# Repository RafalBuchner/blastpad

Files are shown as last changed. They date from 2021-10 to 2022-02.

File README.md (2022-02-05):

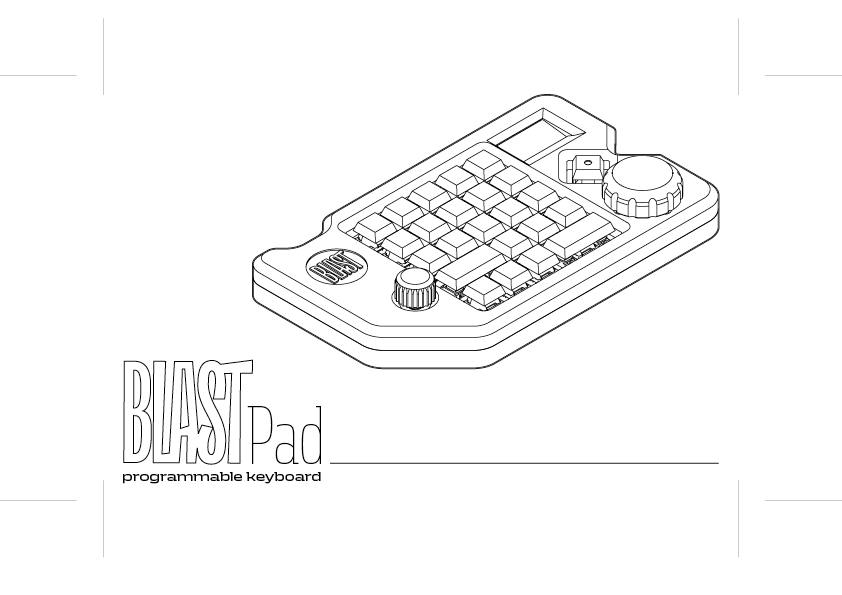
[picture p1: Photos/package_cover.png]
package_cover


# BLASTPad Documentation

**BLASTPad** is a macropad – a programmable keyboard with 23 customazible keys and 2 encoders (knobs). 

# Instruction

## Layout

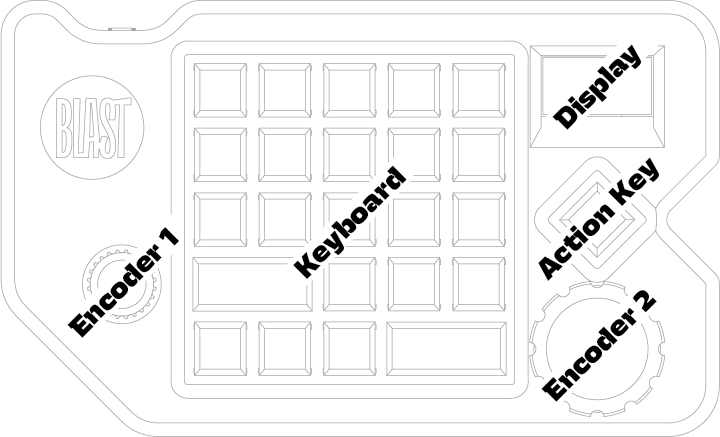
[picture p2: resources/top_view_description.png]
top_view_description


Keyborad's layout was designed to resamble the most left 5 columns of a standard keyborad with the exclusion of the top row (which usually contains all the _F_ keys together with _ESC_ key ). All of the keys are programmable, which means that with the help of a small desktop app you will be able to change behaviour of each key by assigning keystroke combinations to all of them.  Additionally **BLASTPad** has two rotary encoders, which also can trigger some keystroke actions.

## First Run

1. Connect your **BLASTPad** to your computer via USB MICRO B cable. New usb storage device called **BLASTPAD** should appear. We will talk about it more later.
2. Wait until **BLAST** logo will disappear.
3. You should see the similar data on the display:

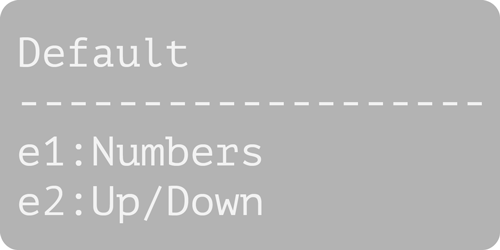
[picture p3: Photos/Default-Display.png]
Default-Display


- "Default" is a title of currently active **Preset**.
- "Numbers" is a title of an **Encoder Action** currently assigned to the **Encoder 1**
- "Up/Down" is a title of an **Encoder Action** currently assigned to the **Encoder 2**

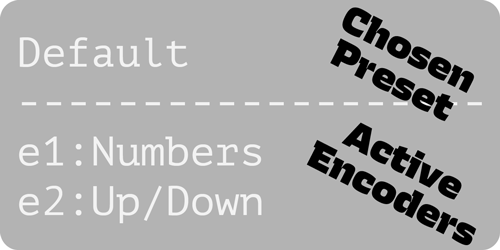
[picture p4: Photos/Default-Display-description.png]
Default-Display-description


### Encoder Basics

In next the chapter we will talk more about **Presets** and how to set them up together with the **Key and Encoder Actions**.  For now let's focus on the behaviour of the latter.

#### Changing the Encoder Actions:

Push the knob like it were a button.

You can see on the display that encoder changed it's title and therefore it changed its behaviour. Each **Preset** has its own set of "behaviours" that can be assigned to eighter **Encoder 1** or **Encoder 2** (see chapter **Creating and editing Presets** to learn how to create those behaviours).

There are two **types of Encoder Actions**:

- **"Left/Right" Encoder Action**

  >  In this action you have assigned two keystrokes to the encoder: one to the counterclockwise and the other one to the cockwise movements.
  >
  > Good example is the "Up/Down" action. Left movement performs "UP ARROW" keystroke, while right movement performs "DOWN ARROW" keystroke. Test it, for example, in some text editor. You will see that the cursor behaves in a similar way, as you would hit the arrow buttons.

- **"Carousel" Encoder Action**

  >"Numbers" is a good example of a carousel action. In this action when you rotate knob clockwise, it will execute numerical keystroke. With every step the keystroke will represent incremented digit starting from *0* (zero) until it will reach the *9*. After this, the counting will reset to *0*.
  >
  >If you'll rotate know counterclockwise, the operation will work almost the same. Except, this time instead of incrementing, it will decrement digits.

## Creating and editing Presets

**Preset** is a singular set of instructions, which determines what keystroke sequence will be triggered by your keys or encoders. You can store almost as many presets on your **BlastPad** as you want.

#### Maximum number of actions in the Preset:

Each **Preset** has actions assigned to the keys, which max number in the preset is equal to the number of the buttons in **BLASTPad**'s keyboard layout (23 – excluding the special lonely key on the right side of the device). Besides **Key Actions**, each preset can have **Encoder Actions**. Number of those is in theory limitless. You can switch between all of **Preset**'s **Encoder Actions** with just two physical encoders. 

#### BlastPadControl app

### MacOS

>  (Currently alpha pre-release version.)

#### Opening the app

Download the zip file from this site:

https://github.com/RafalBuchner/blastpad/releases/download/v0.0.0.1-alpha/BlastPadControl.macOS.zip

Or go to the main GitHub page of this project (https://github.com/RafalBuchner/blastpad) and look for the link in the download section of the documentation. 

Inside the unzipped folder you will find BlastPadControl executable file. Double click on it. The window like one below should appear:

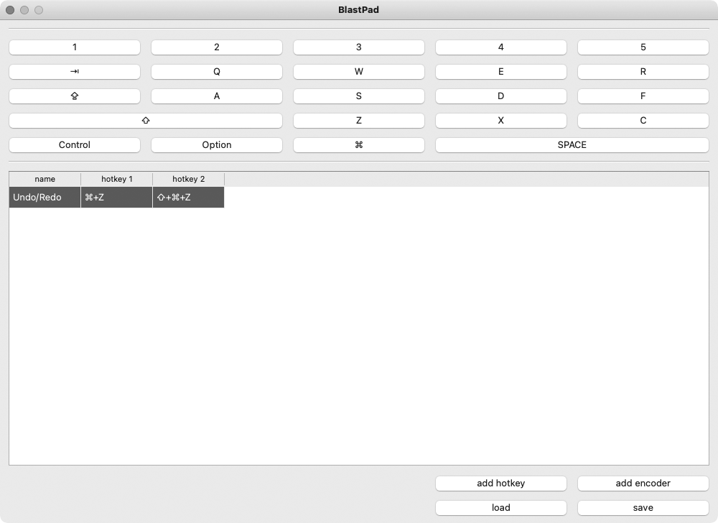
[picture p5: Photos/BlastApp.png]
BlastApp


This is the **Preset** Editor. It is divided into two sections. One is responsible for controling the **Key Actions**. The other one for creating and editing the **Encoder Actions**.

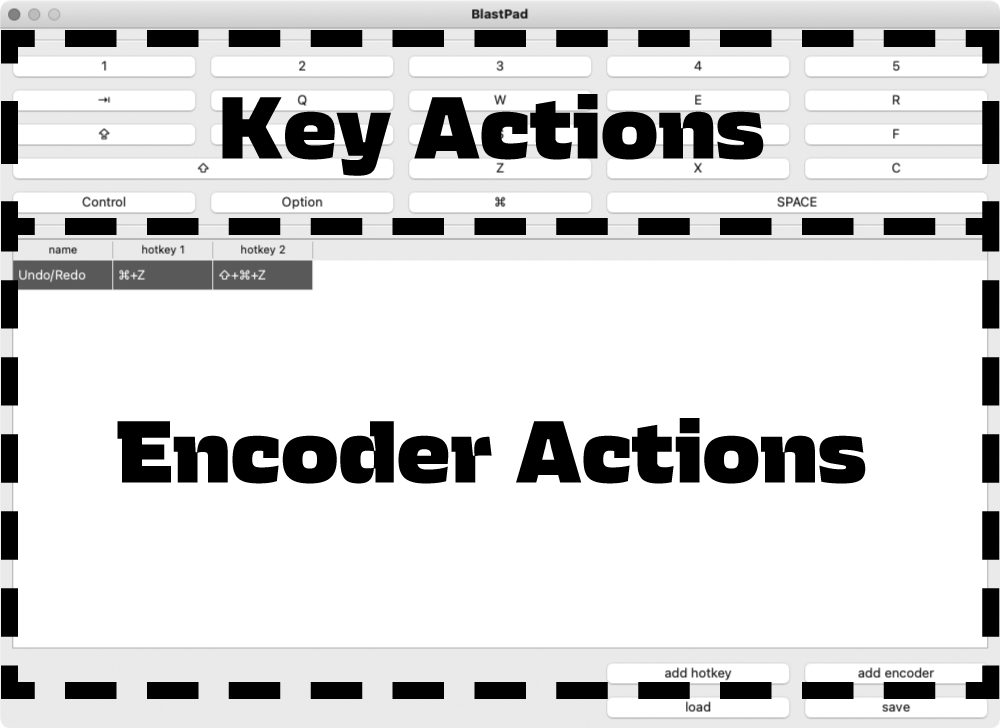
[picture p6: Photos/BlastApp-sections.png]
BlastApp-sections


### Key Actions Section

**The Key Actions Section**'s buttons recreates the **BlastPad**'s keyboard layout. If you click on the one of the buttons, the popup window will appear.

BlastApp-HotKeyPopUp

In this window you can assign pressed keystroke sequence to the previously selected button on the **Key Action Section**. 

Simply press some keystroke sequence on your everyday-regular-keyboard and press "ok" button (**IMPORTANT**: Pacience, This keystroke won't be triggered by the corresponding key on the **BLASTPad** device yet – we will talk about saving presets onto the device soon).

This way you can edit all of the buttons on the **Key Action Section** layout. It is super easy.

### Encoder Actions Section

**Encoder Actions Section** is a list, where each row represent different **Encoder Actions**. Each column cell (except the one reserved for the name) defines Keystroke/Hotkey.

- To create a new **Encoder Action** hit *"add encoder"* button. It will create a new row. 

- Double click on the cell with the title "new encoder" to set the **Encoder Action**'s name that will appear on the **BLASTPad**'s display.

- Click on one of the hotkey cells to assign keystroke sequence.

### Creating "Left/Right" Encoder Action

To create a **"Left/Right" Encoder Action** you have to assign 2 hotkeys to the encoder. One in the column "hotkey 1" and the otherone in the column "hotkey 2". 

The first one will be triggered when you rotate physical encoder counterclockwise. The second, whenever you rotate the same encoder in clockwise direction.

### Creating "Carousel" Encoder Action

To create a **"Carousel" Encoder Action** you have to assign any number of hotkeys, except 2.

If you want to have additional hotkey slots created, hit *"add hotkey"* button. You can add as many as you want.

### Saving presets onto the device

You save **Presets** as separate files with **.json* extension. 

Press *Save* button to create a **Preset** file. In order to save preset on your **BLASTPad** find the usb device with the same name and save the **Preset** into *"Configs"* folder. The name of the file will be used as a **Preset Title** on the **BlastPad**'s display, so name it accordingly to your needs.

### Changing the active Presets on the BlastPad device.

If you have more than one **Presets** you will be able to swich between the presets whenever you like!

It is super easy. Hold **Action Key** (the lonley key on the right side of the device). You will enter the **Preset Selection** menu. Now, rotate your **Encoder 1** while holding the key. This way you will switch between the **Presets**.

### Windows 

> (It is currently under construction. Beta version is coming very soon.)

# Downloads

## BlastPadControl

### [MacOS Download link](https://github.com/RafalBuchner/blastpad/releases/download/v0.0.0.1-alpha/BlastPadControl.macOS.zip)

## Photos

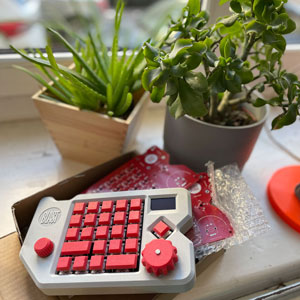
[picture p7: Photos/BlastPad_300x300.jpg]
BlastPad_300x300


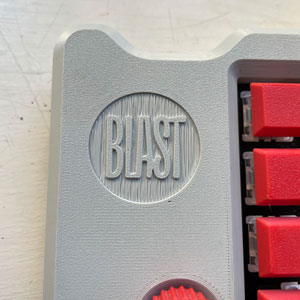
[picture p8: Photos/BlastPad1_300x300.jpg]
BlastPad1_300x300


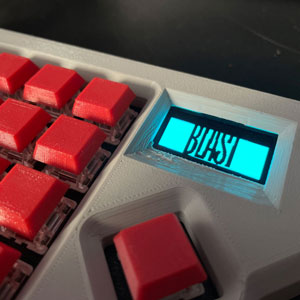
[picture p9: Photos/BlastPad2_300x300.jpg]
BlastPad2_300x300


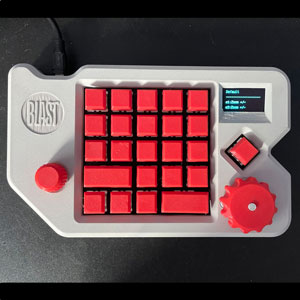
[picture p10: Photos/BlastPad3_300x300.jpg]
BlastPad3_300x300


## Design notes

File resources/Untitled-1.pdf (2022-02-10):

/.notdef AÁĂÂÄÀĀĄÅÃÆǼBCĆČÇĈĊDÐĎĐEÉĔĚÊËĖÈĒĘFGĞĜĢĠHĦĤIĲÍĬÎÏİÌĪĮĨJĴKĶLĹĽĻ ĿŁMNŃŇŅŊÑOÓŎÔÖÒŐŌØÕŒPÞQRŔŘŖSŚŠŞŜȘẞTŦŤŢȚUÚŬÛÜÙŰŪŲŮŨVWẂŴẄẀ XYÝŶŸỲZŹŽŻ/J.ss04/Jcircumflex.ss04/Q.ss05/R.ss06/Racute.ss06/Rcaron.ss06/uni0156. ss06 aáăâäàāąåãæǽbcćčçĉċdðďđeéĕěêëėèēęfgğĝģġhħĥiıíĭîï/i.loclTRK ìĳīįĩjȷĵkķĸlĺľ ļŀłmnńŉňņ ŋñoóŏôöòőōøõœpþqrŕřŗsśšşŝșßtŧťţțuúŭûüùűūųůũvwẃŵẅẁxyýŷÿỳzźžż/d.ss01/dcaron.ss01/ dcroat.ss01/i.ss01/dotlessi.ss01/iacute.ss01/ibreve.ss01/icircumflex.ss01/idieresis.ss01/i.locl-TRK.ss01/igrave.ss01/ij.ss01/imacron.ss01/iogonek.ss01/itilde.ss01/j.ss01/uni0237.ss01/jcircumflex.ss01/l.ss01/lacute.ss01/lcaron.ss01/uni013C.ss01/ldot.ss01/lslash.ss01/u.ss01/uacute. ss01/ubreve.ss01/ucircumflex.ss01/udieresis.ss01/ugrave.ss01/uhungarumlaut.ss01/umacron. ss01/uogonek.ss01/uring.ss01/utilde.ss01/y.ss01/yacute.ss01/ycircumflex.ss01/ydieresis.ss01/ ygrave.ss01/a.ss02/aacute.ss02/abreve.ss02/acircumflex.ss02/adieresis.ss02/agrave.ss02/ amacron.ss02/aogonek.ss02/aring.ss02/atilde.ss02/y.ss02/yacute.ss02/ycircumflex.ss02/ ydieresis.ss02/ygrave.ss02/g.ss03/gbreve.ss03/gcircumflex.ss03/uni0123.ss03/gdotaccent. ss03/f_f/f_f_i/f_f_l fifl/f_f_t.dlig/f_l.dlig/f_t.dlig/t_t.dlig/f_l.dlig.ss01/f_f_i.ss01/f_f_l.ss01/fi.ss01/ fl.ss01 ªºΔΩμπ0123456789➀➁➂➃➄➅➆➇➈➊➋➌➍➎➏➐➑➒/four.sansSerifCircled.ss07/four. sansSerifBlackCircled.ss07/four.ss07/zero.tf/one.tf/two.tf/three.tf/four.tf/five.tf/six.tf/seven.tf/eight.tf/nine.tf/four.tf.ss07/u1F10C/u1F10B ⁰¹²³⁴⁵⁶⁷⁸⁹⁄½⅓¼¾/uni2074.ss07 .,:;…!¡?¿·•*#/\/ exclamdown.case/questiondown.case/periodcentered.case/slash.case/backslash.case (){} []/parenleft.case/parenright.case/braceleft.case/braceright.case/bracketleft.case/bracketright.case -–—_/hyphen.case/endash.case/emdash.case ‚„“”‘’«»‹›”’/guillemotleft.case/guillemotright.case/guilsinglleft.case/guilsinglright.case ฿₿¢¤$€ƒ₹£¥⋅+−×÷=≠><≥≤±≈~¬^∞∫∏∑√ ∂µ%‰↑↗→↘↓↙←↖↔↕●○◊▯■□◽◾▲▶◀△▷◁@&¶§©®™°|¦†‡/bar.case/brokenbar.case/ampersand. ss10/ampersand.ss11 ̈̇̀
́̋/uni030C.alt ̧̨̂̌̆̊̃̄̒¨˙`´˝ˆˇ˘˚˜¯¸˛ ̦

/.notdef AÁĂÂÄÀĀĄÅǺÃÆǼBCĆČÇĈĊDÐĎĐEÉĔĚÊËĖÈĒĘFGĞĜĢĠHĦĤIĲÍĬÎÏİÌĪĮĨJĴKĶLĹĽĻĿŁM NŃŇŅŊÑOÓŎÔÖÒŐŌØǾÕŒPÞQRŔŘŖSŚŠŞŜȘẞTŦŤŢȚUÚŬÛÜÙŰŪŲŮŨVWẂŴẄẀXYÝŶŸỲZŹŽ Ż/K.ss01/uni0136.ss01/R.ss01/Racute.ss01/Rcaron.ss01/uni0156.ss01/Q.ss02/D.superior/O.superior/T.superior aáăâäàāąåǻãæǽbcćčçĉċdðďđeéĕěêëėèēęfgğĝģġhħĥiıíĭîï/i.loclTRK ìĳīįĩjȷĵkķĸlĺľļ ŀłmnńŉňņŋñoóŏôöòőōøǿõœpþqrŕřŗsśšşŝșßtŧťţțuúŭûüùűūųůũvwẃŵẅẁxyýŷÿỳzźžż/k.ss01/ uni0137.ss01/kgreenlandic.ss01/ae.ss03/aeacute.ss03/e.ss03/eacute.ss03/ebreve.ss03/ecaron. ss03/ecircumflex.ss03/edieresis.ss03/edotaccent.ss03/egrave.ss03/emacron.ss03/eogonek. ss03/oe.ss03/r.ss04/racute.ss04/rcaron.ss04/uni0157.ss04/y.ss05/yacute.ss05/ycircumflex.ss05/ ydieresis.ss05/ygrave.ss05 fiflªºΔΩμπ0123456789/zero.osf/one.osf/two.osf/three.osf/four.osf/five. osf/six.osf/seven.osf/eight.osf/nine.osf/two.osf.ss06/three.osf.ss06/two.ss06/three.ss06/zero.tf/ one.tf/two.tf/three.tf/four.tf/five.tf/six.tf/seven.tf/eight.tf/nine.tf/two.tf.ss06/three.tf.ss06/zero. tosf/one.tosf/two.tosf/three.tosf/four.tosf/five.tosf/six.tosf/seven.tosf/eight.tosf/nine.tosf/two. tosf.ss06/three.tosf.ss06 ¹²³⁴⁄½¼¾.,:;…!¡?¿·•*⁂#/\⁑/exclamdown.case/questiondown.case/periodcentered.case (){}[]-–—_/hyphen.case/endash.case/emdash.case ‚„“”‘’«»‹›”’/guillemotleft.case/ guillemotright.case/guilsinglleft.case/guilsinglright.case ¢¤$€ƒ£¥⋅+−×÷=≠><≥≤±≈~¬^∞∫Ω∆∏∑√ ∂µ%‰●○◊▯■□◽◾▲▶◀△▷◁⚪⚫@&¶§©®™°|¦†‡/ampersand.ss07 ̈̇
̀

́

̋
/uni030C.alt ̵̧̨̦

̂

̌

̆

̊

̃

̄

̒
¨˙`´˝ˆˇ˘˚˜¯¸˛/uni0308.
case/uni0307.case/gravecomb.case/acutecomb.case/uni030B.case/uni0302.case/uni030C.case/ uni0306.case/uni030A.case/tildecomb.case/uni0304.case/uni0328.case/uni0307.i/ringacutecomb/ringacutecomb.case

/.notdef AÁĂÂÄÀĀĄÅǺÃÆǼBCĆČÇĈĊDÐĎĐEÉĔĚÊËĖÈĒĘFGĞĜĢĠHĦĤIĲÍĬÎÏİÌĪĮĨJĴKĶLĹĽĻĿŁMNŃŇŅ ŊÑOÓŎÔÖÒŐŌØǾÕŒPÞQRŔŘŖSŚŠŞŜȘẞTŦŤŢȚUÚŬÛÜÙŰŪŲŮŨVWẂŴẄẀXYÝŶŸỲZŹŽŻ/Q.ss02/D. superior/O.superior/T.superior aáăâäàāąåǻãæǽbcćčçĉċdðďđeéĕěêëėèēęfgğĝģġhħĥiıíĭîï/i.loclTRK ìĳīįĩjȷĵkķĸlĺľļŀłmnńŉňņŋñoóŏôöòőōøǿõœpþqrŕřŗsśšşŝșßtŧťţțuúŭûüùűūųůũvwẃŵẅẁxyýŷÿỳzźžż/a. ss08/aacute.ss08/abreve.ss08/acircumflex.ss08/adieresis.ss08/agrave.ss08/amacron.ss08/aogonek. ss08/aring.ss08/aringacute.ss08/atilde.ss08 fiflªºΔΩμπ0123456789/zero.osf/one.osf/two.osf/three. osf/four.osf/five.osf/six.osf/seven.osf/eight.osf/nine.osf/two.osf.ss06/three.osf.ss06/two.ss06/three. ss06/zero.tf/one.tf/two.tf/three.tf/four.tf/five.tf/six.tf/seven.tf/eight.tf/nine.tf/two.tf.ss06/three.tf.ss06/ zero.tosf/one.tosf/two.tosf/three.tosf/four.tosf/five.tosf/six.tosf/seven.tosf/eight.tosf/nine.tosf/two. tosf.ss06/three.tosf.ss06 ¹²³⁴⁄½¼¾.,:;…!¡?¿·•*⁂#/\⁑/exclamdown.case/questiondown.case/periodcentered.case (){}[]-–—_/hyphen.case/endash.case/emdash.case ‚„“”‘’«»‹›”’/guillemotleft.case/guillemotright.case/guilsinglleft.case/guilsinglright.case ¢¤$€ƒ£¥⋅+−×÷=≠><≥≤±≈~¬^∞∫Ω∆∏∑√∂µ%‰●○◊▯■ □◽◾▲▶◀△▷◁⚪⚫@&¶§©®™°|¦†‡̈̇
̀

́

̋
/uni030C.alt ̵̧̨̦

̂

̌

̆

̊

̃

̄

̒
¨˙`´˝ˆˇ˘˚˜¯¸˛/uni0308.case/uni0307.case/gravecomb.case/ acutecomb.case/uni030B.case/uni0302.case/uni030C.case/uni0306.case/uni030A.case/tildecomb. case/uni0304.case/uni0328.case/uni0307.i/ringacutecomb/ringacutecomb.case

/.notdef AÁĂÂÄÀĀĄÅǺÃÆǼBCĆČÇĈĊDÐĎĐEÉĔĚÊËĖÈĒĘFGĞĜĢĠHĦĤIĲÍĬÎÏİÌĪĮĨJĴKĶLĹĽĻĿŁM NŃŇŅŊÑOÓŎÔÖÒŐŌØǾÕŒPÞQRŔŘŖSŚŠŞŜȘẞTŦŤŢȚUÚŬÛÜÙŰŪŲŮŨVWẂŴẄẀXYÝŶŸỲ ZŹŽŻ/K.ss03/uni0136.ss03/I.ss06/Iacute.ss06/Ibreve.ss06/Icircumflex.ss06/Idieresis.ss06/ Idotaccent.ss06/Igrave.ss06/Imacron.ss06/Iogonek.ss06/Itilde.ss06/J.ss06/Jcircumflex.ss06 aáăâäàāąåǻãæǽbcćčçĉċdðďđeéĕěêëėèēęfgğĝģġhħĥiıíĭîï/i.loclTRK ìĳīįĩjȷĵkķĸlĺľļŀłmnńŉňņŋñoóŏ ôöòőōøǿõœpþqrŕřŗsśšşŝșßtŧťţțuúŭûüùűūųůũvwẃŵẅẁxyýŷÿỳzźžż/a.ss01/aacute.ss01/abreve. ss01/acircumflex.ss01/adieresis.ss01/agrave.ss01/amacron.ss01/aogonek.ss01/aring.ss01/aringacute.ss01/atilde.ss01/g.ss02/gbreve.ss02/gcircumflex.ss02/uni0123.ss02/gdotaccent.ss02/k. ss03/uni0137.ss03/l.ss04/lacute.ss04/lcaron.ss04/uni013C.ss04/ldot.ss04/lslash.ss04/i.ss05/ dotlessi.ss05/iacute.ss05/ibreve.ss05/icircumflex.ss05/idieresis.ss05/i.loclTRK.ss05/igrave. ss05/imacron.ss05/iogonek.ss05/j.ss05/uni0237.ss05/jcircumflex.ss05/l.ss05/lacute.ss05/ lcaron.ss05/uni013C.ss05/ldot.ss05/lslash.ss05 fi/f_f/f_t/f_f_i/f_f_t/t_t ªºΔΩμπ0123456789/ four.ss10/u1F10B ➀➁➂➃➄➅➆➇➈/four.sansSerifCircled.ss10/u1F10C ➊➋➌➍➎➏➐➑➒/four.sans-SerifBlackCircled.ss10/zero.tf/one.tf/two.tf/three.tf/four.tf/five.tf/six.tf/seven.tf/eight.tf/ nine.tf/four.tf.ss10 ₀₁₂₃₄₅₆₇₈₉/uni2084.ss10/zero.dnom/one.dnom/two.dnom/three.dnom/four. dnom/five.dnom/six.dnom/seven.dnom/eight.dnom/nine.dnom/four.dnom.ss10/zero.numr/ one.numr/two.numr/three.numr/four.numr/five.numr/six.numr/seven.numr/eight.numr/nine. numr/four.numr.ss10 ⁰¹²³⁴⁵⁶⁷⁸⁹/uni2074.ss10 ⁄½¼¾⅛⅜⅝⅞.,:;…!¡?¿·•*⁂#/\⁑/exclamdown.case/ questiondown.case/periodcentered.case/slash.case/backslash.case (){}[]/parenleft.case/parenright.case/braceleft.case/braceright.case/bracketleft.case/bracketright.case -–—_/hyphen. case/endash.case/emdash.case ‚„“”‘’«»‹›”’/guillemotleft.case/guillemotright.case/guilsinglleft. case/guilsinglright.case ¢¤$€ƒ£¥/dollar.alt ⋅+−×÷=≠><≥≤±≈~¬^∞∫Ω∆∏∑√∂µ%‰◊@&¶§©®™°|¦†‡¨ `´˝ˆˇ˘˚˜¯¸˛˙/ringacutecomb/ringacutecomb.case ↑↗→↘↓↙←↖↔↕↶↷⬆⬈⬊⬇⬋⬅⬉➡○●◗◆⬢⬡◇▯■□◽ ◾▲▶◀△▷◁/u1F697 /u1F322/u1F50B/u1F50C ☇/u1F527 ➤⚑/u1F6D2/u1F50D ⊖⊕✔⏵⏸⏭⏹⏺⟳↺↻/u1F508/u1F509/u1F50A/u1F4F9 /u1F4A9/u1F512/ u1F513 ⏰✉/u1F585/u1F56E/u1F6EB/u1F4AC ☺☻☹/u1F641 ♡/u1F494/u1F44D/u1F44E ☽⏾☁☎☮★✦✚✜✖✺❋▥▨

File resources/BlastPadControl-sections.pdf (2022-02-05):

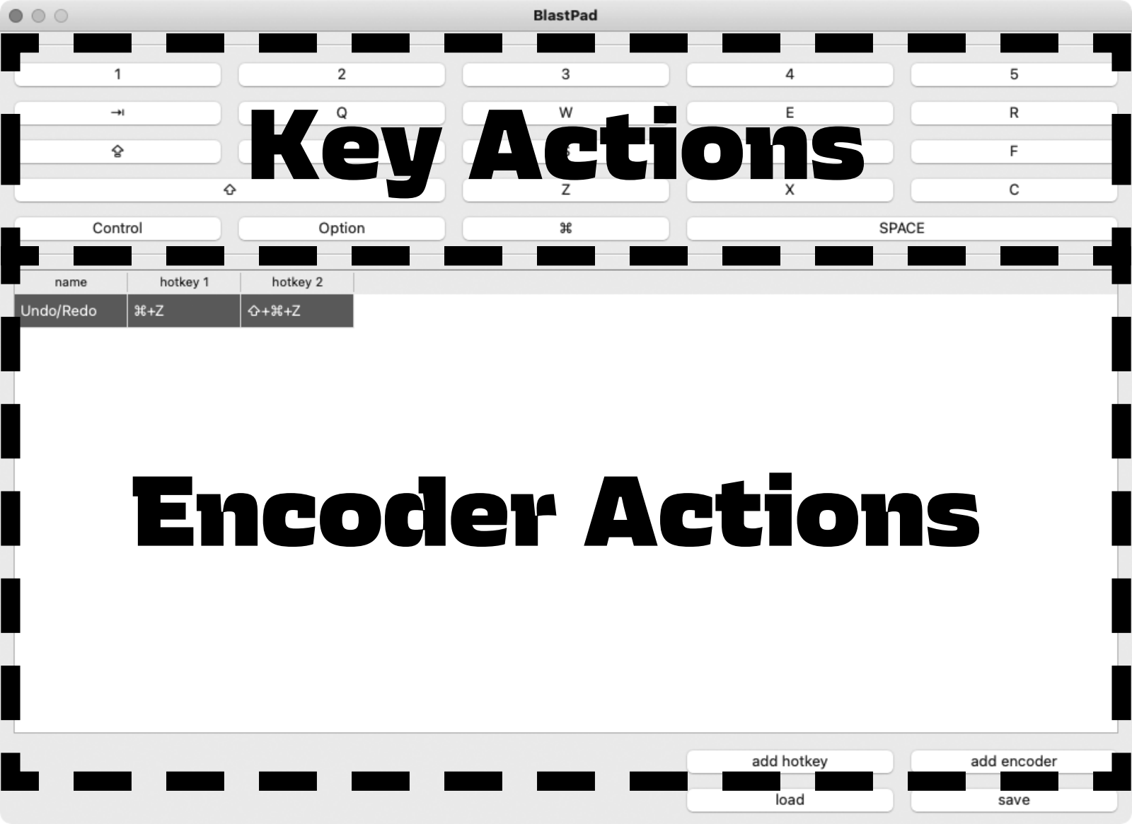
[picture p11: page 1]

Key Actions

Encoder Actions

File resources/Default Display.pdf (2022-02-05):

Default
–––––––––––––––––––
e1:Numbers
e2:Up/Down

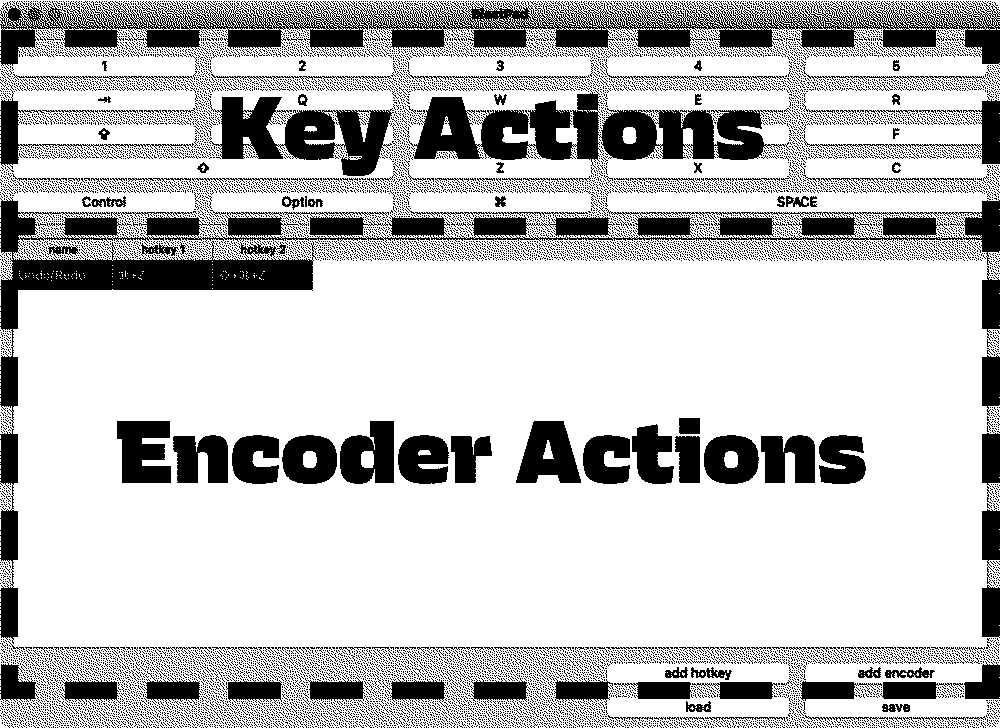
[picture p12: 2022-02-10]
Photos/BlastApp-sections_bw.png

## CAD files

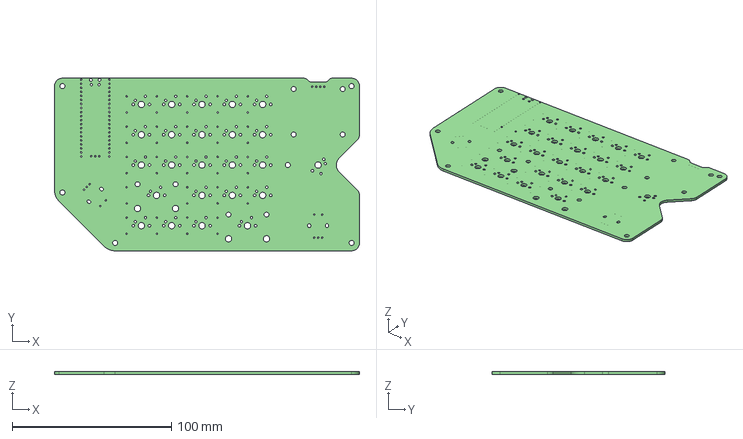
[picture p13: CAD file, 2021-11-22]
hardware/KiCAD-Keyboard-Tutorial-master/blastpad.step
191.7 x 108.5 x 1.60 mm
Pico

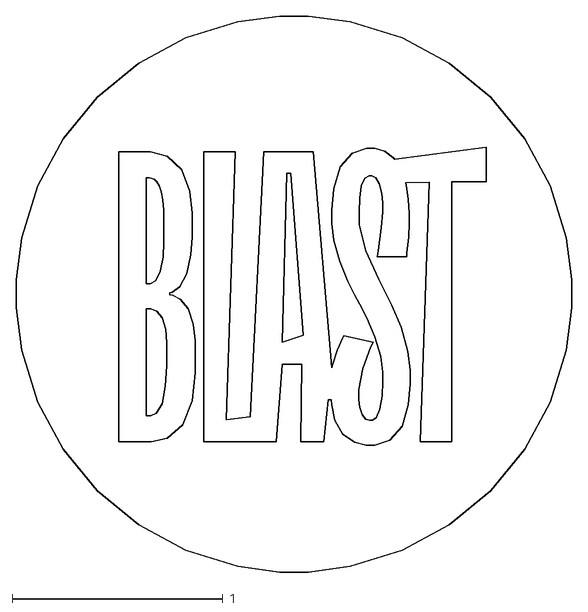
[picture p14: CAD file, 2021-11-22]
hardware/KiCAD-Keyboard-Tutorial-master/BLAST 190px.dxf
2.64 x 2.64

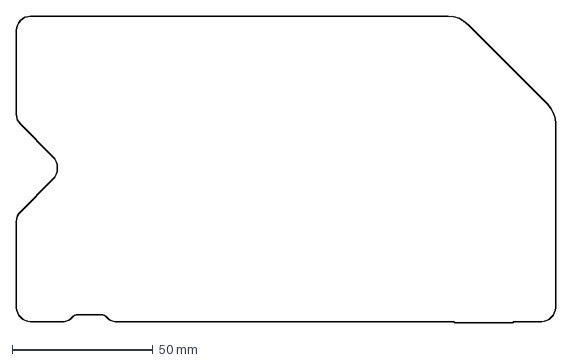
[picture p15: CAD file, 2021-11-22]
hardware/KiCAD-Keyboard-Tutorial-master/outline.dxf
191.7 x 108.9 mm

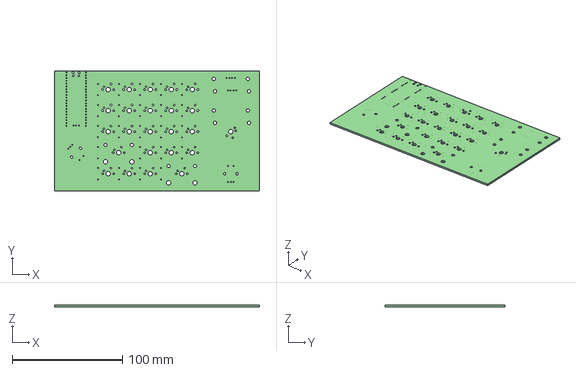
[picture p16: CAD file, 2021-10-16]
hardware/KiCAD-Keyboard-Tutorial-master/360.step
185.6 x 109.0 x 1.60 mm
Pico

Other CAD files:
hardware/KiCAD-Keyboard-Tutorial-master/tutorial.step
hardware/KiCAD-Keyboard-Tutorial-master/test.stp
hardware/KiCAD-Keyboard-Tutorial-master/360.stp

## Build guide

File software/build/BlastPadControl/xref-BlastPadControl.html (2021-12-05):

# modulegraph cross reference for BlastPadControl.py, pyi_rth_inspect.py, pyi_rth_multiprocessing.py, pyi_rth_pkgutil.py, pyi_rth_pyqt5.py

BlastPadControl.py Script

imports: PyQt5 • PyQt5.QtCore • PyQt5.QtGui • PyQt5.QtWidgets • _bootlocale • _collections_abc • _weakrefset • abc • codecs • collections • collections.abc • copy • copyreg • encodings • encodings.aliases • encodings.ascii • encodings.base64_codec • encodings.big5 • encodings.big5hkscs • encodings.bz2_codec • encodings.charmap • encodings.cp037 • encodings.cp1006 • encodings.cp1026 • encodings.cp1125 • encodings.cp1140 • encodings.cp1250 • encodings.cp1251 • encodings.cp1252 • encodings.cp1253 • encodings.cp1254 • encodings.cp1255 • encodings.cp1256 • encodings.cp1257 • encodings.cp1258 • encodings.cp273 • encodings.cp424 • encodings.cp437 • encodings.cp500 • encodings.cp720 • encodings.cp737 • encodings.cp775 • encodings.cp850 • encodings.cp852 • encodings.cp855 • encodings.cp856 • encodings.cp857 • encodings.cp858 • encodings.cp860 • encodings.cp861 • encodings.cp862 • encodings.cp863 • encodings.cp864 • encodings.cp865 • encodings.cp866 • encodings.cp869 • encodings.cp874 • encodings.cp875 • encodings.cp932 • encodings.cp949 • encodings.cp950 • encodings.euc_jis_2004 • encodings.euc_jisx0213 • encodings.euc_jp • encodings.euc_kr • encodings.gb18030 • encodings.gb2312 • encodings.gbk • encodings.hex_codec • encodings.hp_roman8 • encodings.hz • encodings.idna • encodings.iso2022_jp • encodings.iso2022_jp_1 • encodings.iso2022_jp_2 • encodings.iso2022_jp_2004 • encodings.iso2022_jp_3 • encodings.iso2022_jp_ext • encodings.iso2022_kr • encodings.iso8859_1 • encodings.iso8859_10 • encodings.iso8859_11 • encodings.iso8859_13 • encodings.iso8859_14 • encodings.iso8859_15 • encodings.iso8859_16 • encodings.iso8859_2 • encodings.iso8859_3 • encodings.iso8859_4 • encodings.iso8859_5 • encodings.iso8859_6 • encodings.iso8859_7 • encodings.iso8859_8 • encodings.iso8859_9 • encodings.johab • encodings.koi8_r • encodings.koi8_t • encodings.koi8_u • encodings.kz1048 • encodings.latin_1 • encodings.mac_arabic • encodings.mac_croatian • encodings.mac_cyrillic • encodings.mac_farsi • encodings.mac_greek • encodings.mac_iceland • encodings.mac_latin2 • encodings.mac_roman • encodings.mac_romanian • encodings.mac_turkish • encodings.mbcs • encodings.oem • encodings.palmos • encodings.ptcp154 • encodings.punycode • encodings.quopri_codec • encodings.raw_unicode_escape • encodings.rot_13 • encodings.shift_jis • encodings.shift_jis_2004 • encodings.shift_jisx0213 • encodings.tis_620 • encodings.undefined • encodings.unicode_escape • encodings.utf_16 • encodings.utf_16_be • encodings.utf_16_le • encodings.utf_32 • encodings.utf_32_be • encodings.utf_32_le • encodings.utf_7 • encodings.utf_8 • encodings.utf_8_sig • encodings.uu_codec • encodings.zlib_codec • enum • functools • heapq • io • json • keyword • linecache • locale • operator • os • pprint • pyi_rth_inspect.py • pyi_rth_multiprocessing.py • pyi_rth_pkgutil.py • pyi_rth_pyqt5.py • re • reprlib • sre_compile • sre_constants • sre_parse • sys • traceback • types • warnings • weakref

pyi_rth_inspect.py Script

imports: inspect • os • sys

imported by: BlastPadControl.py

pyi_rth_multiprocessing.py Script

imports: multiprocessing • multiprocessing.popen_fork • multiprocessing.popen_spawn_posix • multiprocessing.popen_spawn_win32 • multiprocessing.spawn • os • subprocess • sys

imported by: BlastPadControl.py

pyi_rth_pkgutil.py Script

imports: os • pkgutil • pyimod03_importers • sys

imported by: BlastPadControl.py

pyi_rth_pyqt5.py Script

imports: os • sys

imported by: BlastPadControl.py

'java.lang' MissingModule

imported by: platform • xml.sax._exceptions

'org.python' MissingModule

imported by: copy • xml.sax

PyQt5 Package

imports: PyQt5.QtCore • PyQt5.QtGui • PyQt5.QtWidgets • PyQt5.sip

imported by: BlastPadControl.py • PyQt5.QtCore • PyQt5.QtGui • PyQt5.QtWidgets • PyQt5.sip

PyQt5.QtCore /Users/rafalbuchner/Documents/blastpad/venv/lib/python3.9/site-packages/PyQt5/QtCore.abi3.so

imports: PyQt5 • PyQt5.QtCore

imported by: BlastPadControl.py • PyQt5 • PyQt5.QtCore • PyQt5.QtGui • PyQt5.QtWidgets

PyQt5.QtGui /Users/rafalbuchner/Documents/blastpad/venv/lib/python3.9/site-packages/PyQt5/QtGui.abi3.so

imports: PyQt5 • PyQt5.QtCore • PyQt5.QtGui

imported by: BlastPadControl.py • PyQt5 • PyQt5.QtGui • PyQt5.QtWidgets

PyQt5.QtWidgets /Users/rafalbuchner/Documents/blastpad/venv/lib/python3.9/site-packages/PyQt5/QtWidgets.abi3.so

imports: PyQt5 • PyQt5.QtCore • PyQt5.QtGui • PyQt5.QtWidgets

imported by: BlastPadControl.py • PyQt5 • PyQt5.QtWidgets

PyQt5.sip /Users/rafalbuchner/Documents/blastpad/venv/lib/python3.9/site-packages/PyQt5/sip.cpython-39-darwin.so

imports: PyQt5

imported by: PyQt5

__future__ SourceModule

imported by: codeop • doctest

_abc (builtin module)

imported by: abc

_aix_support SourceModule

imports: _bootsubprocess • subprocess • sys • sysconfig

imported by: distutils.util • sysconfig

_ast (builtin module)

imported by: ast

_asyncio /Library/Frameworks/Python.framework/Versions/3.9/lib/python3.9/lib-dynload/_asyncio.cpython-39-darwin.so

imported by: asyncio.events • asyncio.futures • asyncio.tasks

_bisect /Library/Frameworks/Python.framework/Versions/3.9/lib/python3.9/lib-dynload/_bisect.cpython-39-darwin.so

imported by: bisect

_blake2 /Library/Frameworks/Python.framework/Versions/3.9/lib/python3.9/lib-dynload/_blake2.cpython-39-darwin.so

imported by: hashlib

_bootlocale SourceModule

imports: _locale • locale • sys

imported by: BlastPadControl.py • locale

_bootsubprocess SourceModule

imports: os

imported by: _aix_support

_bz2 /Library/Frameworks/Python.framework/Versions/3.9/lib/python3.9/lib-dynload/_bz2.cpython-39-darwin.so

imported by: bz2

_codecs (builtin module)

imported by: codecs

_codecs_cn /Library/Frameworks/Python.framework/Versions/3.9/lib/python3.9/lib-dynload/_codecs_cn.cpython-39-darwin.so

imported by: encodings.gb18030 • encodings.gb2312 • encodings.gbk • encodings.hz

_codecs_hk /Library/Frameworks/Python.framework/Versions/3.9/lib/python3.9/lib-dynload/_codecs_hk.cpython-39-darwin.so

imported by: encodings.big5hkscs

_codecs_iso2022 /Library/Frameworks/Python.framework/Versions/3.9/lib/python3.9/lib-dynload/_codecs_iso2022.cpython-39-darwin.so

imported by: encodings.iso2022_jp • encodings.iso2022_jp_1 • encodings.iso2022_jp_2 • encodings.iso2022_jp_2004 • encodings.iso2022_jp_3 • encodings.iso2022_jp_ext • encodings.iso2022_kr

_codecs_jp /Library/Frameworks/Python.framework/Versions/3.9/lib/python3.9/lib-dynload/_codecs_jp.cpython-39-darwin.so

imported by: encodings.cp932 • encodings.euc_jis_2004 • encodings.euc_jisx0213 • encodings.euc_jp • encodings.shift_jis • encodings.shift_jis_2004 • encodings.shift_jisx0213

_codecs_kr /Library/Frameworks/Python.framework/Versions/3.9/lib/python3.9/lib-dynload/_codecs_kr.cpython-39-darwin.so

imported by: encodings.cp949 • encodings.euc_kr • encodings.johab

_codecs_tw /Library/Frameworks/Python.framework/Versions/3.9/lib/python3.9/lib-dynload/_codecs_tw.cpython-39-darwin.so

imported by: encodings.big5 • encodings.cp950

_collections (builtin module)

imported by: collections • threading

_collections_abc SourceModule

imports: abc • sys • warnings

imported by: BlastPadControl.py • collections • collections.abc • contextlib • locale • os • pathlib • random • types • weakref

_compat_pickle SourceModule

imported by: _pickle • pickle

_compression SourceModule

imports: io

imported by: bz2 • gzip • lzma

_contextvars /Library/Frameworks/Python.framework/Versions/3.9/lib/python3.9/lib-dynload/_contextvars.cpython-39-darwin.so

imported by: contextvars

_csv /Library/Frameworks/Python.framework/Versions/3.9/lib/python3.9/lib-dynload/_csv.cpython-39-darwin.so

imported by: csv

_ctypes /Library/Frameworks/Python.framework/Versions/3.9/lib/python3.9/lib-dynload/_ctypes.cpython-39-darwin.so

imported by: ctypes • ctypes.macholib.dyld

_datetime /Library/Frameworks/Python.framework/Versions/3.9/lib/python3.9/lib-dynload/_datetime.cpython-39-darwin.so

imports: _strptime • time

imported by: datetime

_decimal /Library/Frameworks/Python.framework/Versions/3.9/lib/python3.9/lib-dynload/_decimal.cpython-39-darwin.so

imported by: decimal

_elementtree /Library/Frameworks/Python.framework/Versions/3.9/lib/python3.9/lib-dynload/_elementtree.cpython-39-darwin.so

imports: pyexpat • xml.etree.ElementInclude • xml.etree.ElementPath • xml.etree.ElementTree • xml.etree.cElementTree

imported by: xml.etree.ElementTree

_frozen_importlib ExcludedModule

imported by: importlib • importlib.abc • zipimport

_frozen_importlib_external MissingModule

imported by: importlib • importlib._bootstrap • importlib.abc • zipimport

_functools (builtin module)

imported by: functools

_hashlib /Library/Frameworks/Python.framework/Versions/3.9/lib/python3.9/lib-dynload/_hashlib.cpython-39-darwin.so

imported by: hashlib • hmac

_heapq /Library/Frameworks/Python.framework/Versions/3.9/lib/python3.9/lib-dynload/_heapq.cpython-39-darwin.so

imported by: heapq

_imp (builtin module)

imported by: distutils.sysconfig • importlib • importlib._bootstrap_external • importlib.machinery • importlib.util • sysconfig • zipimport

_io (builtin module)

imported by: importlib._bootstrap_external • io • zipimport

_json /Library/Frameworks/Python.framework/Versions/3.9/lib/python3.9/lib-dynload/_json.cpython-39-darwin.so

imports: json.decoder

imported by: json.decoder • json.encoder • json.scanner

_locale (builtin module)

imported by: _bootlocale • locale • re

_lzma /Library/Frameworks/Python.framework/Versions/3.9/lib/python3.9/lib-dynload/_lzma.cpython-39-darwin.so

imported by: lzma

_md5 /Library/Frameworks/Python.framework/Versions/3.9/lib/python3.9/lib-dynload/_md5.cpython-39-darwin.so

imported by: hashlib

_multibytecodec /Library/Frameworks/Python.framework/Versions/3.9/lib/python3.9/lib-dynload/_multibytecodec.cpython-39-darwin.so

imported by: encodings.big5 • encodings.big5hkscs • encodings.cp932 • encodings.cp949 • encodings.cp950 • encodings.euc_jis_2004 • encodings.euc_jisx0213 • encodings.euc_jp • encodings.euc_kr • encodings.gb18030 • encodings.gb2312 • encodings.gbk • encodings.hz • encodings.iso2022_jp • encodings.iso2022_jp_1 • encodings.iso2022_jp_2 • encodings.iso2022_jp_2004 • encodings.iso2022_jp_3 • encodings.iso2022_jp_ext • encodings.iso2022_kr • encodings.johab • encodings.shift_jis • encodings.shift_jis_2004 • encodings.shift_jisx0213

_multiprocessing /Library/Frameworks/Python.framework/Versions/3.9/lib/python3.9/lib-dynload/_multiprocessing.cpython-39-darwin.so

imported by: multiprocessing.connection • multiprocessing.queues • multiprocessing.resource_tracker • multiprocessing.synchronize

_opcode /Library/Frameworks/Python.framework/Versions/3.9/lib/python3.9/lib-dynload/_opcode.cpython-39-darwin.so

imported by: opcode

_operator (builtin module)

imported by: hmac • operator

_osx_support SourceModule

imports: contextlib • distutils • distutils.log • os • re • sys • tempfile

imported by: distutils.sysconfig • distutils.util • sysconfig

_overlapped MissingModule

imported by: asyncio.windows_events

_pickle /Library/Frameworks/Python.framework/Versions/3.9/lib/python3.9/lib-dynload/_pickle.cpython-39-darwin.so

imports: _compat_pickle • codecs • copyreg

imported by: pickle

_posixshmem /Library/Frameworks/Python.framework/Versions/3.9/lib/python3.9/lib-dynload/_posixshmem.cpython-39-darwin.so

imported by: multiprocessing.resource_tracker • multiprocessing.shared_memory

_posixsubprocess /Library/Frameworks/Python.framework/Versions/3.9/lib/python3.9/lib-dynload/_posixsubprocess.cpython-39-darwin.so

imports: gc

imported by: multiprocessing.util • subprocess

_py_abc SourceModule

imports: _weakrefset

imported by: abc

_pydecimal SourceModule

imports: collections • contextvars • itertools • locale • math • numbers • re • sys

imported by: decimal

_queue /Library/Frameworks/Python.framework/Versions/3.9/lib/python3.9/lib-dynload/_queue.cpython-39-darwin.so

imported by: queue

_random /Library/Frameworks/Python.framework/Versions/3.9/lib/python3.9/lib-dynload/_random.cpython-39-darwin.so

imported by: random

_scproxy /Library/Frameworks/Python.framework/Versions/3.9/lib/python3.9/lib-dynload/_scproxy.cpython-39-darwin.so

imported by: urllib.request

_sha1 /Library/Frameworks/Python.framework/Versions/3.9/lib/python3.9/lib-dynload/_sha1.cpython-39-darwin.so

imported by: hashlib

_sha256 /Library/Frameworks/Python.framework/Versions/3.9/lib/python3.9/lib-dynload/_sha256.cpython-39-darwin.so

imported by: hashlib

_sha3 /Library/Frameworks/Python.framework/Versions/3.9/lib/python3.9/lib-dynload/_sha3.cpython-39-darwin.so

imported by: hashlib

_sha512 /Library/Frameworks/Python.framework/Versions/3.9/lib/python3.9/lib-dynload/_sha512.cpython-39-darwin.so

imported by: hashlib • random

_signal (builtin module)

imported by: signal

_socket /Library/Frameworks/Python.framework/Versions/3.9/lib/python3.9/lib-dynload/_socket.cpython-39-darwin.so

imported by: socket

_sre (builtin module)

imports: copy • re

imported by: sre_compile • sre_constants

_ssl /Library/Frameworks/Python.framework/Versions/3.9/lib/python3.9/lib-dynload/_ssl.cpython-39-darwin.so

imports: socket

imported by: ssl

_stat (builtin module)

imported by: stat

_statistics /Library/Frameworks/Python.framework/Versions/3.9/lib/python3.9/lib-dynload/_statistics.cpython-39-darwin.so

imported by: statistics

_string (builtin module)

imported by: string

_strptime SourceModule

imports: _thread • calendar • datetime • locale • re • time

imported by: _datetime • datetime • time

_struct /Library/Frameworks/Python.framework/Versions/3.9/lib/python3.9/lib-dynload/_struct.cpython-39-darwin.so

imported by: struct

_sysconfigdata__darwin_darwin SourceModule

imported by: distutils • sysconfig

_thread (builtin module)

imported by: _strptime • asyncio.base_futures • functools • reprlib • tempfile • test.support • threading

_threading_local SourceModule

imports: contextlib • threading • weakref

imported by: threading

_tracemalloc (builtin module)

imported by: tracemalloc

_warnings (builtin module)

imported by: importlib._bootstrap_external • warnings

_weakref (builtin module)

imported by: _weakrefset • collections • weakref • xml.sax.expatreader

_weakrefset SourceModule

imports: _weakref • types

imported by: BlastPadControl.py • _py_abc • multiprocessing.process • threading • weakref

_winapi MissingModule

imported by: asyncio.windows_events • asyncio.windows_utils • encodings • multiprocessing.connection • multiprocessing.heap • multiprocessing.popen_spawn_win32 • multiprocessing.reduction • multiprocessing.shared_memory • multiprocessing.spawn • subprocess • test.support

_winreg MissingModule

imported by: platform

abc SourceModule

imports: _abc • _py_abc

imported by: BlastPadControl.py • _collections_abc • contextlib • email._policybase • functools • importlib.abc • importlib.metadata • inspect • io • multiprocessing.reduction • numbers • os • selectors • typing

argparse SourceModule

imports: copy • gettext • os • re • shutil • sys • textwrap • warnings

imported by: ast • calendar • code • dis • doctest • gzip • http.server • inspect • tarfile • tokenize • unittest.main • zipfile

array /Library/Frameworks/Python.framework/Versions/3.9/lib/python3.9/lib-dynload/array.cpython-39-darwin.so

imported by: multiprocessing.dummy • multiprocessing.managers • multiprocessing.reduction • socket

ast SourceModule

imports: _ast • argparse • collections • contextlib • enum • inspect • sys • warnings

imported by: inspect

asyncio Package

imports: asyncio • asyncio.DefaultEventLoopPolicy • asyncio.base_events • asyncio.base_futures • asyncio.base_subprocess • asyncio.base_tasks • asyncio.constants • asyncio.coroutines • asyncio.events • asyncio.exceptions • asyncio.format_helpers • asyncio.futures • asyncio.locks • asyncio.proactor_events • asyncio.protocols • asyncio.queues • asyncio.runners • asyncio.selector_events • asyncio.sslproto • asyncio.staggered • asyncio.streams • asyncio.subprocess • asyncio.tasks • asyncio.threads • asyncio.transports • asyncio.trsock • asyncio.unix_events • asyncio.windows_events • asyncio.windows_utils • sys

imported by: asyncio • asyncio.base_events • asyncio.base_futures • asyncio.base_subprocess • asyncio.base_tasks • asyncio.constants • asyncio.coroutines • asyncio.events • asyncio.exceptions • asyncio.format_helpers • asyncio.futures • asyncio.locks • asyncio.log • asyncio.proactor_events • asyncio.protocols • asyncio.queues • asyncio.runners • asyncio.selector_events • asyncio.sslproto • asyncio.staggered • asyncio.streams • asyncio.subprocess • asyncio.tasks • asyncio.threads • asyncio.transports • asyncio.trsock • asyncio.unix_events • asyncio.windows_events • asyncio.windows_utils • unittest.async_case

asyncio.DefaultEventLoopPolicy MissingModule

imported by: asyncio • asyncio.events

asyncio.base_events SourceModule

imports: asyncio • asyncio.constants • asyncio.coroutines • asyncio.events • asyncio.exceptions • asyncio.futures • asyncio.log • asyncio.protocols • asyncio.sslproto • asyncio.staggered • asyncio.tasks • asyncio.transports • asyncio.trsock • collections • collections.abc • concurrent.futures • functools • heapq • itertools • os • socket • ssl • stat • subprocess • sys • threading • time • traceback • warnings • weakref

imported by: asyncio • asyncio.proactor_events • asyncio.selector_events • asyncio.unix_events

asyncio.base_futures SourceModule

imports: _thread • asyncio • asyncio.format_helpers • reprlib

imported by: asyncio • asyncio.base_tasks • asyncio.coroutines • asyncio.futures

asyncio.base_subprocess SourceModule

imports: asyncio • asyncio.log • asyncio.protocols • asyncio.transports • collections • subprocess • warnings

imported by: asyncio • asyncio.unix_events • asyncio.windows_events

asyncio.base_tasks SourceModule

imports: asyncio • asyncio.base_futures • asyncio.coroutines • linecache • traceback

imported by: asyncio • asyncio.tasks

asyncio.constants SourceModule

imports: asyncio • enum

imported by: asyncio • asyncio.base_events • asyncio.coroutines • asyncio.format_helpers • asyncio.proactor_events • asyncio.selector_events • asyncio.sslproto • asyncio.unix_events

asyncio.coroutines SourceModule

imports: asyncio • asyncio.base_futures • asyncio.constants • asyncio.format_helpers • asyncio.log • collections.abc • functools • inspect • os • sys • traceback • types • warnings

imported by: asyncio • asyncio.base_events • asyncio.base_tasks • asyncio.runners • asyncio.streams • asyncio.tasks • asyncio.unix_events

asyncio.events SourceModule

imports: _asyncio • asyncio • asyncio.DefaultEventLoopPolicy • asyncio.format_helpers • contextvars • os • socket • subprocess • sys • threading

imported by: asyncio • asyncio.base_events • asyncio.futures • asyncio.locks • asyncio.queues • asyncio.runners • asyncio.selector_events • asyncio.staggered • asyncio.streams • asyncio.subprocess • asyncio.tasks • asyncio.threads • asyncio.unix_events • asyncio.windows_events • test.support

asyncio.exceptions SourceModule

imports: asyncio

imported by: asyncio • asyncio.base_events • asyncio.futures • asyncio.locks • asyncio.proactor_events • asyncio.staggered • asyncio.streams • asyncio.tasks • asyncio.unix_events • asyncio.windows_events

asyncio.format_helpers SourceModule

imports: asyncio • asyncio.constants • functools • inspect • reprlib • sys • traceback

imported by: asyncio • asyncio.base_futures • asyncio.coroutines • asyncio.events • asyncio.futures • asyncio.streams

asyncio.futures SourceModule

imports: _asyncio • asyncio • asyncio.base_futures • asyncio.events • asyncio.exceptions • asyncio.format_helpers • concurrent.futures • contextvars • logging • sys

imported by: asyncio • asyncio.base_events • asyncio.proactor_events • asyncio.selector_events • asyncio.tasks • asyncio.unix_events • asyncio.windows_events

asyncio.locks SourceModule

imports: asyncio • asyncio.events • asyncio.exceptions • collections • warnings

imported by: asyncio • asyncio.queues • asyncio.staggered

asyncio.log SourceModule

imports: asyncio • logging

imported by: asyncio.base_events • asyncio.base_subprocess • asyncio.coroutines • asyncio.proactor_events • asyncio.selector_events • asyncio.sslproto • asyncio.streams • asyncio.subprocess • asyncio.unix_events • asyncio.windows_events

asyncio.proactor_events SourceModule

imports: asyncio • asyncio.base_events • asyncio.constants • asyncio.exceptions • asyncio.futures • asyncio.log • asyncio.protocols • asyncio.sslproto • asyncio.transports • asyncio.trsock • collections • io • os • signal • socket • threading • warnings

imported by: asyncio • asyncio.windows_events

asyncio.protocols SourceModule

imports: asyncio

imported by: asyncio • asyncio.base_events • asyncio.base_subprocess • asyncio.proactor_events • asyncio.selector_events • asyncio.sslproto • asyncio.streams • asyncio.subprocess

asyncio.queues SourceModule

imports: asyncio • asyncio.events • asyncio.locks • collections • heapq • warnings

imported by: asyncio • asyncio.tasks

asyncio.runners SourceModule

imports: asyncio • asyncio.coroutines • asyncio.events • asyncio.tasks

imported by: asyncio

asyncio.selector_events SourceModule

imports: asyncio • asyncio.base_events • asyncio.constants • asyncio.events • asyncio.futures • asyncio.log • asyncio.protocols • asyncio.sslproto • asyncio.transports • asyncio.trsock • collections • errno • functools • selectors • socket • ssl • warnings • weakref

imported by: asyncio • asyncio.unix_events • asyncio.windows_events

asyncio.sslproto SourceModule

imports: asyncio • asyncio.constants • asyncio.log • asyncio.protocols • asyncio.transports • collections • ssl • warnings

imported by: asyncio • asyncio.base_events • asyncio.proactor_events • asyncio.selector_events

asyncio.staggered SourceModule

imports: asyncio • asyncio.events • asyncio.exceptions • asyncio.locks • asyncio.tasks • contextlib • typing

imported by: asyncio • asyncio.base_events

asyncio.streams SourceModule

imports: asyncio • asyncio.coroutines • asyncio.events • asyncio.exceptions • asyncio.format_helpers • asyncio.log • asyncio.protocols • asyncio.tasks • socket • sys • warnings • weakref

imported by: asyncio • asyncio.subprocess

asyncio.subprocess SourceModule

imports: asyncio • asyncio.events • asyncio.log • asyncio.protocols • asyncio.streams • asyncio.tasks • subprocess • warnings

imported by: asyncio

asyncio.tasks SourceModule

imports: _asyncio • asyncio • asyncio.base_tasks • asyncio.coroutines • asyncio.events • asyncio.exceptions • asyncio.futures • asyncio.queues • concurrent.futures • contextvars • functools • inspect • itertools • types • warnings • weakref

imported by: asyncio • asyncio.base_events • asyncio.runners • asyncio.staggered • asyncio.streams • asyncio.subprocess • asyncio.unix_events • asyncio.windows_events

asyncio.threads SourceModule

imports: asyncio • asyncio.events • contextvars • functools

imported by: asyncio

asyncio.transports SourceModule

imports: asyncio

imported by: asyncio • asyncio.base_events • asyncio.base_subprocess • asyncio.proactor_events • asyncio.selector_events • asyncio.sslproto • asyncio.unix_events

asyncio.trsock SourceModule

imports: asyncio • socket • warnings

imported by: asyncio • asyncio.base_events • asyncio.proactor_events • asyncio.selector_events

asyncio.unix_events SourceModule

imports: asyncio • asyncio.base_events • asyncio.base_subprocess • asyncio.constants • asyncio.coroutines • asyncio.events • asyncio.exceptions • asyncio.futures • asyncio.log • asyncio.selector_events • asyncio.tasks • asyncio.transports • errno • io • itertools • os • selectors • signal • socket • stat • subprocess • sys • threading • warnings

imported by: asyncio

asyncio.windows_events SourceModule

imports: _overlapped • _winapi • asyncio • asyncio.base_subprocess • asyncio.events • asyncio.exceptions • asyncio.futures • asyncio.log • asyncio.proactor_events • asyncio.selector_events • asyncio.tasks • asyncio.windows_utils • errno • math • msvcrt • socket • struct • time • weakref

imported by: asyncio

asyncio.windows_utils SourceModule

imports: _winapi • asyncio • itertools • msvcrt • os • subprocess • sys • tempfile • warnings

imported by: asyncio • asyncio.windows_events

atexit (builtin module)

imported by: logging • multiprocessing.util • weakref

base64 SourceModule

imports: binascii • getopt • re • struct • sys

imported by: email._encoded_words • email.base64mime • email.encoders • encodings.base64_codec • http.server • secrets • ssl • urllib.request • xmlrpc.client

bdb SourceModule

imports: fnmatch • inspect • linecache • os • reprlib • sys

imported by: pdb

binascii /Library/Frameworks/Python.framework/Versions/3.9/lib/python3.9/lib-dynload/binascii.cpython-39-darwin.so

imported by: base64 • email._encoded_words • email.base64mime • email.contentmanager • email.header • encodings.hex_codec • encodings.uu_codec • http.server • plistlib • quopri • secrets • uu • zipfile

bisect SourceModule

imports: _bisect

imported by: multiprocessing.heap • random • statistics • urllib.request

builtins (builtin module)

imported by: bz2 • codecs • doctest • gettext • gzip • inspect • locale • lzma • operator • pydoc • reprlib • subprocess • tarfile • tokenize • warnings

bz2 SourceModule

imports: _bz2 • _compression • builtins • io • os • threading

imported by: encodings.bz2_codec • shutil • tarfile • test.support • zipfile

calendar SourceModule

imports: argparse • datetime • itertools • locale • sys

imported by: _strptime • email._parseaddr • http.cookiejar • ssl

cmd SourceModule

imports: readline • string • sys

imported by: pdb

code SourceModule

imports: argparse • codeop • readline • sys • traceback

imported by: pdb

codecs SourceModule

imports: _codecs • builtins • encodings • sys

imported by: BlastPadControl.py • _pickle • encodings • encodings.ascii • encodings.base64_codec • encodings.big5 • encodings.big5hkscs • encodings.bz2_codec • encodings.charmap • encodings.cp037 • encodings.cp1006 • encodings.cp1026 • encodings.cp1125 • encodings.cp1140 • encodings.cp1250 • encodings.cp1251 • encodings.cp1252 • encodings.cp1253 • encodings.cp1254 • encodings.cp1255 • encodings.cp1256 • encodings.cp1257 • encodings.cp1258 • encodings.cp273 • encodings.cp424 • encodings.cp437 • encodings.cp500 • encodings.cp720 • encodings.cp737 • encodings.cp775 • encodings.cp850 • encodings.cp852 • encodings.cp855 • encodings.cp856 • encodings.cp857 • encodings.cp858 • encodings.cp860 • encodings.cp861 • encodings.cp862 • encodings.cp863 • encodings.cp864 • encodings.cp865 • encodings.cp866 • encodings.cp869 • encodings.cp874 • encodings.cp875 • encodings.cp932 • encodings.cp949 • encodings.cp950 • encodings.euc_jis_2004 • encodings.euc_jisx0213 • encodings.euc_jp • encodings.euc_kr • encodings.gb18030 • encodings.gb2312 • encodings.gbk • encodings.hex_codec • encodings.hp_roman8 • encodings.hz • encodings.idna • encodings.iso2022_jp • encodings.iso2022_jp_1 • encodings.iso2022_jp_2 • encodings.iso2022_jp_2004 • encodings.iso2022_jp_3 • encodings.iso2022_jp_ext • encodings.iso2022_kr • encodings.iso8859_1 • encodings.iso8859_10 • encodings.iso8859_11 • encodings.iso8859_13 • encodings.iso8859_14 • encodings.iso8859_15 • encodings.iso8859_16 • encodings.iso8859_2 • encodings.iso8859_3 • encodings.iso8859_4 • encodings.iso8859_5 • encodings.iso8859_6 • encodings.iso8859_7 • encodings.iso8859_8 • encodings.iso8859_9 • encodings.johab • encodings.koi8_r • encodings.koi8_t • encodings.koi8_u • encodings.kz1048 • encodings.latin_1 • encodings.mac_arabic • encodings.mac_croatian • encodings.mac_cyrillic • encodings.mac_farsi • encodings.mac_greek • encodings.mac_iceland • encodings.mac_latin2 • encodings.mac_roman • encodings.mac_romanian • encodings.mac_turkish • encodings.mbcs • encodings.oem • encodings.palmos • encodings.ptcp154 • encodings.punycode • encodings.quopri_codec • encodings.raw_unicode_escape • encodings.rot_13 • encodings.shift_jis • encodings.shift_jis_2004 • encodings.shift_jisx0213 • encodings.tis_620 • encodings.undefined • encodings.unicode_escape • encodings.utf_16 • encodings.utf_16_be • encodings.utf_16_le • encodings.utf_32 • encodings.utf_32_be • encodings.utf_32_le • encodings.utf_7 • encodings.utf_8 • encodings.utf_8_sig • encodings.uu_codec • encodings.zlib_codec • json • lib2to3.pgen2.tokenize • pickle • plistlib • tokenize • xml.sax.saxutils

codeop SourceModule

imports: __future__ • warnings

imported by: code

collections Package

imports: _collections • _collections_abc • _weakref • copy • heapq • itertools • keyword • operator • reprlib • sys • warnings

imported by: BlastPadControl.py • _pydecimal • ast • asyncio.base_events • asyncio.base_subprocess • asyncio.locks • asyncio.proactor_events • asyncio.queues • asyncio.selector_events • asyncio.sslproto • collections.abc • concurrent.futures._base • configparser • contextlib • difflib • dis • doctest • email.feedparser • functools • importlib.metadata • inspect • lib2to3.btm_matcher • lib2to3.refactor • multiprocessing.heap • multiprocessing.pool • multiprocessing.queues • pkgutil • platform • pprint • pydoc • queue • selectors • shlex • shutil • ssl • statistics • string • threading • tokenize • traceback • typing • unittest._log • unittest.case • unittest.util • urllib.parse • xml.etree.ElementTree

collections.abc SourceModule

imports: _collections_abc • collections

imported by: BlastPadControl.py • asyncio.base_events • asyncio.coroutines • configparser • http.client • inspect • logging • selectors • test.support • tracemalloc • typing • xml.etree.ElementTree

concurrent Package

imported by: concurrent.futures

concurrent.futures Package

imports: concurrent • concurrent.futures._base • concurrent.futures.process • concurrent.futures.thread

imported by: asyncio.base_events • asyncio.futures • asyncio.tasks • concurrent.futures._base • concurrent.futures.process • concurrent.futures.thread

concurrent.futures._base SourceModule

imports: collections • concurrent.futures • logging • threading • time • types

imported by: concurrent.futures • concurrent.futures.process • concurrent.futures.thread

concurrent.futures.process SourceModule

imports: concurrent.futures • concurrent.futures._base • functools • itertools • multiprocessing • multiprocessing.connection • multiprocessing.queues • os • queue • sys • threading • traceback • weakref

imported by: concurrent.futures

concurrent.futures.thread SourceModule

imports: concurrent.futures • concurrent.futures._base • itertools • os • queue • threading • types • weakref

imported by: concurrent.futures

configparser SourceModule

imports: collections • collections.abc • functools • io • itertools • os • re • sys • warnings

imported by: importlib.metadata

contextlib SourceModule

imports: _collections_abc • abc • collections • functools • sys • types

imported by: _osx_support • _threading_local • ast • asyncio.staggered • getpass • glob • http.server • importlib.metadata • importlib.util • subprocess • test.support • typing • unittest.case • urllib.request • xml.etree.ElementTree • zipfile

contextvars SourceModule

imports: _contextvars

imported by: _pydecimal • asyncio.events • asyncio.futures • asyncio.tasks • asyncio.threads

copy SourceModule

imports: 'org.python' • copyreg • types • weakref

imported by: BlastPadControl.py • _sre • argparse • collections • email.generator • gettext • http.cookiejar • http.server • tarfile • weakref • webbrowser • xml.etree.ElementInclude

copyreg SourceModule

imported by: BlastPadControl.py • _pickle • copy • multiprocessing.reduction • pickle • re

csv SourceModule

imports: _csv • io • re

imported by: importlib.metadata

ctypes Package

imports: _ctypes • ctypes._endian • nt • os • struct • sys • types

imported by: ctypes._aix • ctypes._endian • ctypes.macholib • ctypes.util • ctypes.wintypes • multiprocessing.sharedctypes • test.support

ctypes._endian SourceModule

imports: ctypes • sys

imported by: ctypes

datetime SourceModule

imports: _datetime • _strptime • math • sys • time • warnings

imported by: _strptime • calendar • email.utils • http.cookiejar • http.server • plistlib • test.support.testresult • xmlrpc.client

decimal SourceModule

imports: _decimal • _pydecimal

imported by: fractions • statistics • test.support • xmlrpc.client

difflib SourceModule

imports: collections • difflib • heapq • re • types

imported by: difflib • doctest • unittest.case

dis SourceModule

imports: argparse • collections • io • opcode • sys • types

imported by: inspect • pdb

distutils Package

imports: _sysconfigdata__darwin_darwin • distutils.ccompiler • distutils.log • distutils.sysconfig • sys

imported by: _osx_support • distutils.ccompiler • distutils.debug • distutils.dep_util • distutils.dir_util • distutils.errors • distutils.fancy_getopt • distutils.file_util • distutils.filelist • distutils.log • distutils.spawn • distutils.sysconfig • distutils.text_file • distutils.util • test.support

distutils.ccompiler SourceModule

imports: distutils • distutils.debug • distutils.dep_util • distutils.dir_util • distutils.errors • distutils.fancy_getopt • distutils.file_util • distutils.log • distutils.spawn • distutils.util • os • re • sys • tempfile

imported by: distutils • test.support

distutils.debug SourceModule

imports: distutils • os

imported by: distutils.ccompiler • distutils.filelist • distutils.spawn

distutils.dep_util SourceModule

imports: distutils • distutils.errors • os • stat

imported by: distutils.ccompiler • distutils.file_util • distutils.util

distutils.dir_util SourceModule

imports: distutils • distutils.errors • distutils.file_util • distutils.log • errno • os

imported by: distutils.ccompiler • distutils.util

distutils.errors SourceModule

imports: distutils

imported by: distutils.ccompiler • distutils.dep_util • distutils.dir_util • distutils.fancy_getopt • distutils.file_util • distutils.filelist • distutils.spawn • distutils.sysconfig • distutils.util • test.support

distutils.fancy_getopt SourceModule

imports: distutils • distutils.errors • getopt • re • string • sys

imported by: distutils.ccompiler

distutils.file_util SourceModule

imports: distutils • distutils.dep_util • distutils.errors • distutils.log • errno • os • posixpath • stat

imported by: distutils.ccompiler • distutils.dir_util • distutils.util

distutils.filelist SourceModule

imports: distutils • distutils.debug • distutils.errors • distutils.log • distutils.util • fnmatch • functools • os • re

imported by: distutils.util

distutils.log SourceModule

imports: distutils • sys

imported by: _osx_support • distutils • distutils.ccompiler • distutils.dir_util • distutils.file_util • distutils.filelist • distutils.spawn • distutils.util

distutils.spawn SourceModule

imports: distutils • distutils.debug • distutils.errors • distutils.log • distutils.sysconfig • os • subprocess • sys

imported by: distutils.ccompiler • distutils.util • test.support

distutils.sysconfig SourceModule

imports: _imp • _osx_support • distutils • distutils.errors • distutils.text_file • os • re • sys • warnings

imported by: distutils • distutils.spawn • distutils.util • test.support

distutils.text_file SourceModule

imports: distutils • io • sys

imported by: distutils.sysconfig

distutils.util SourceModule

imports: _aix_support • _osx_support • distutils • distutils.dep_util • distutils.dir_util • distutils.errors • distutils.file_util • distutils.filelist • distutils.log • distutils.spawn • distutils.sysconfig • importlib.util • os • pwd • py_compile • re • string • subprocess • sys • tempfile

imported by: distutils.ccompiler • distutils.filelist

doctest SourceModule

imports: __future__ • argparse • builtins • collections • difflib • inspect • io • linecache • os • pdb • re • sys • traceback • unittest

imported by: pickle • test.support

email Package

imports: email._header_value_parser • email.charset • email.errors • email.header • email.parser

imported by: email._encoded_words • email._header_value_parser • email._parseaddr • email._policybase • email.base64mime • email.charset • email.contentmanager • email.encoders • email.errors • email.feedparser • email.generator • email.header • email.headerregistry • email.iterators • email.message • email.parser • email.policy • email.quoprimime • email.utils • importlib.metadata • urllib.request

email._encoded_words SourceModule

imports: base64 • binascii • email • email.errors • functools • re • string

imported by: email._header_value_parser • email.message

email._header_value_parser SourceModule

imports: email • email._encoded_words • email.errors • email.utils • operator • re • string • sys • urllib

imported by: email • email.headerregistry

email._parseaddr SourceModule

imports: calendar • email • time

imported by: email.utils

email._policybase SourceModule

imports: abc • email • email.charset • email.header • email.utils

imported by: email.feedparser • email.message • email.parser • email.policy

email.base64mime SourceModule

imports: base64 • binascii • email

imported by: email.charset • email.header

email.charset SourceModule

imports: email • email.base64mime • email.encoders • email.errors • email.quoprimime • functools

imported by: email • email._policybase • email.contentmanager • email.header • email.message • email.utils

email.contentmanager SourceModule

imports: binascii • email • email.charset • email.errors • email.message • email.quoprimime

imported by: email.policy

email.encoders SourceModule

imports: base64 • email • quopri

imported by: email.charset

email.errors SourceModule

imports: email

imported by: email • email._encoded_words • email._header_value_parser • email.charset • email.contentmanager • email.feedparser • email.header • email.headerregistry • email.message

email.feedparser SourceModule

imports: collections • email • email._policybase • email.errors • email.message • io • re

imported by: email.parser

email.generator SourceModule

imports: copy • email • email.utils • io • random • re • sys • time

imported by: email.message

email.header SourceModule

imports: binascii • email • email.base64mime • email.charset • email.errors • email.quoprimime • re

imported by: email • email._policybase

email.headerregistry SourceModule

imports: email • email._header_value_parser • email.errors • email.utils • types

imported by: email.policy

email.iterators SourceModule

imports: email • io • sys

imported by: email.message

email.message SourceModule

imports: email • email._encoded_words • email._policybase • email.charset • email.errors • email.generator • email.iterators • email.policy • email.utils • io • quopri • re • uu

imported by: email.contentmanager • email.feedparser • email.policy • http.client • pydoc

email.parser SourceModule

imports: email • email._policybase • email.feedparser • io

imported by: email • http.client

email.policy SourceModule

imports: email • email._policybase • email.contentmanager • email.headerregistry • email.message • email.utils • re • sys

imported by: email.message

email.quoprimime SourceModule

imports: email • re • string

imported by: email.charset • email.contentmanager • email.header

email.utils SourceModule

imports: datetime • email • email._parseaddr • email.charset • os • random • re • socket • time • urllib.parse

imported by: email._header_value_parser • email._policybase • email.generator • email.headerregistry • email.message • email.policy • http.server • urllib.request

encodings Package

imports: _winapi • codecs • encodings • encodings.aliases • encodings.ascii • encodings.base64_codec • encodings.big5 • encodings.big5hkscs • encodings.bz2_codec • encodings.charmap • encodings.cp037 • encodings.cp1006 • encodings.cp1026 • encodings.cp1125 • encodings.cp1140 • encodings.cp1250 • encodings.cp1251 • encodings.cp1252 • encodings.cp1253 • encodings.cp1254 • encodings.cp1255 • encodings.cp1256 • encodings.cp1257 • encodings.cp1258 • encodings.cp273 • encodings.cp424 • encodings.cp437 • encodings.cp500 • encodings.cp720 • encodings.cp737 • encodings.cp775 • encodings.cp850 • encodings.cp852 • encodings.cp855 • encodings.cp856 • encodings.cp857 • encodings.cp858 • encodings.cp860 • encodings.cp861 • encodings.cp862 • encodings.cp863 • encodings.cp864 • encodings.cp865 • encodings.cp866 • encodings.cp869 • encodings.cp874 • encodings.cp875 • encodings.cp932 • encodings.cp949 • encodings.cp950 • encodings.euc_jis_2004 • encodings.euc_jisx0213 • encodings.euc_jp • encodings.euc_kr • encodings.gb18030 • encodings.gb2312 • encodings.gbk • encodings.hex_codec • encodings.hp_roman8 • encodings.hz • encodings.idna • encodings.iso2022_jp • encodings.iso2022_jp_1 • encodings.iso2022_jp_2 • encodings.iso2022_jp_2004 • encodings.iso2022_jp_3 • encodings.iso2022_jp_ext • encodings.iso2022_kr • encodings.iso8859_1 • encodings.iso8859_10 • encodings.iso8859_11 • encodings.iso8859_13 • encodings.iso8859_14 • encodings.iso8859_15 • encodings.iso8859_16 • encodings.iso8859_2 • encodings.iso8859_3 • encodings.iso8859_4 • encodings.iso8859_5 • encodings.iso8859_6 • encodings.iso8859_7 • encodings.iso8859_8 • encodings.iso8859_9 • encodings.johab • encodings.koi8_r • encodings.koi8_t • encodings.koi8_u • encodings.kz1048 • encodings.latin_1 • encodings.mac_arabic • encodings.mac_croatian • encodings.mac_cyrillic • encodings.mac_farsi • encodings.mac_greek • encodings.mac_iceland • encodings.mac_latin2 • encodings.mac_roman • encodings.mac_romanian • encodings.mac_turkish • encodings.mbcs • encodings.oem • encodings.palmos • encodings.ptcp154 • encodings.punycode • encodings.quopri_codec • encodings.raw_unicode_escape • encodings.rot_13 • encodings.shift_jis • encodings.shift_jis_2004 • encodings.shift_jisx0213 • encodings.tis_620 • encodings.undefined • encodings.unicode_escape • encodings.utf_16 • encodings.utf_16_be • encodings.utf_16_le • encodings.utf_32 • encodings.utf_32_be • encodings.utf_32_le • encodings.utf_7 • encodings.utf_8 • encodings.utf_8_sig • encodings.uu_codec • encodings.zlib_codec • sys

imported by: BlastPadControl.py • codecs • encodings • encodings.aliases • encodings.ascii • encodings.base64_codec • encodings.big5 • encodings.big5hkscs • encodings.bz2_codec • encodings.charmap • encodings.cp037 • encodings.cp1006 • encodings.cp1026 • encodings.cp1125 • encodings.cp1140 • encodings.cp1250 • encodings.cp1251 • encodings.cp1252 • encodings.cp1253 • encodings.cp1254 • encodings.cp1255 • encodings.cp1256 • encodings.cp1257 • encodings.cp1258 • encodings.cp273 • encodings.cp424 • encodings.cp437 • encodings.cp500 • encodings.cp720 • encodings.cp737 • encodings.cp775 • encodings.cp850 • encodings.cp852 • encodings.cp855 • encodings.cp856 • encodings.cp857 • encodings.cp858 • encodings.cp860 • encodings.cp861 • encodings.cp862 • encodings.cp863 • encodings.cp864 • encodings.cp865 • encodings.cp866 • encodings.cp869 • encodings.cp874 • encodings.cp875 • encodings.cp932 • encodings.cp949 • encodings.cp950 • encodings.euc_jis_2004 • encodings.euc_jisx0213 • encodings.euc_jp • encodings.euc_kr • encodings.gb18030 • encodings.gb2312 • encodings.gbk • encodings.hex_codec • encodings.hp_roman8 • encodings.hz • encodings.idna • encodings.iso2022_jp • encodings.iso2022_jp_1 • encodings.iso2022_jp_2 • encodings.iso2022_jp_2004 • encodings.iso2022_jp_3 • encodings.iso2022_jp_ext • encodings.iso2022_kr • encodings.iso8859_1 • encodings.iso8859_10 • encodings.iso8859_11 • encodings.iso8859_13 • encodings.iso8859_14 • encodings.iso8859_15 • encodings.iso8859_16 • encodings.iso8859_2 • encodings.iso8859_3 • encodings.iso8859_4 • encodings.iso8859_5 • encodings.iso8859_6 • encodings.iso8859_7 • encodings.iso8859_8 • encodings.iso8859_9 • encodings.johab • encodings.koi8_r • encodings.koi8_t • encodings.koi8_u • encodings.kz1048 • encodings.latin_1 • encodings.mac_arabic • encodings.mac_croatian • encodings.mac_cyrillic • encodings.mac_farsi • encodings.mac_greek • encodings.mac_iceland • encodings.mac_latin2 • encodings.mac_roman • encodings.mac_romanian • encodings.mac_turkish • encodings.mbcs • encodings.oem • encodings.palmos • encodings.ptcp154 • encodings.punycode • encodings.quopri_codec • encodings.raw_unicode_escape • encodings.rot_13 • encodings.shift_jis • encodings.shift_jis_2004 • encodings.shift_jisx0213 • encodings.tis_620 • encodings.undefined • encodings.unicode_escape • encodings.utf_16 • encodings.utf_16_be • encodings.utf_16_le • encodings.utf_32 • encodings.utf_32_be • encodings.utf_32_le • encodings.utf_7 • encodings.utf_8 • encodings.utf_8_sig • encodings.uu_codec • encodings.zlib_codec • locale

encodings.aliases SourceModule

imports: encodings

imported by: BlastPadControl.py • encodings • locale

encodings.ascii SourceModule

imports: codecs • encodings

imported by: BlastPadControl.py • encodings

encodings.base64_codec SourceModule

imports: base64 • codecs • encodings

imported by: BlastPadControl.py • encodings

encodings.big5 SourceModule

imports: _codecs_tw • _multibytecodec • codecs • encodings

imported by: BlastPadControl.py • encodings

encodings.big5hkscs SourceModule

imports: _codecs_hk • _multibytecodec • codecs • encodings

imported by: BlastPadControl.py • encodings

encodings.bz2_codec SourceModule

imports: bz2 • codecs • encodings

imported by: BlastPadControl.py • encodings

encodings.charmap SourceModule

imports: codecs • encodings

imported by: BlastPadControl.py • encodings

encodings.cp037 SourceModule

imports: codecs • encodings

imported by: BlastPadControl.py • encodings

encodings.cp1006 SourceModule

imports: codecs • encodings

imported by: BlastPadControl.py • encodings

encodings.cp1026 SourceModule

imports: codecs • encodings

imported by: BlastPadControl.py • encodings

encodings.cp1125 SourceModule

imports: codecs • encodings

imported by: BlastPadControl.py • encodings

encodings.cp1140 SourceModule

imports: codecs • encodings

imported by: BlastPadControl.py • encodings

encodings.cp1250 SourceModule

imports: codecs • encodings

imported by: BlastPadControl.py • encodings

encodings.cp1251 SourceModule

imports: codecs • encodings

imported by: BlastPadControl.py • encodings

encodings.cp1252 SourceModule

imports: codecs • encodings

imported by: BlastPadControl.py • encodings

encodings.cp1253 SourceModule

imports: codecs • encodings

imported by: BlastPadControl.py • encodings

encodings.cp1254 SourceModule

imports: codecs • encodings

imported by: BlastPadControl.py • encodings

encodings.cp1255 SourceModule

imports: codecs • encodings

imported by: BlastPadControl.py • encodings

encodings.cp1256 SourceModule

imports: codecs • encodings

imported by: BlastPadControl.py • encodings

encodings.cp1257 SourceModule

imports: codecs • encodings

imported by: BlastPadControl.py • encodings

encodings.cp1258 SourceModule

imports: codecs • encodings

imported by: BlastPadControl.py • encodings

encodings.cp273 SourceModule

imports: codecs • encodings

imported by: BlastPadControl.py • encodings

encodings.cp424 SourceModule

imports: codecs • encodings

imported by: BlastPadControl.py • encodings

encodings.cp437 SourceModule

imports: codecs • encodings

imported by: BlastPadControl.py • encodings

encodings.cp500 SourceModule

imports: codecs • encodings

imported by: BlastPadControl.py • encodings

encodings.cp720 SourceModule

imports: codecs • encodings

imported by: BlastPadControl.py • encodings

encodings.cp737 SourceModule

imports: codecs • encodings

imported by: BlastPadControl.py • encodings

encodings.cp775 SourceModule

imports: codecs • encodings

imported by: BlastPadControl.py • encodings

encodings.cp850 SourceModule

imports: codecs • encodings

imported by: BlastPadControl.py • encodings

encodings.cp852 SourceModule

imports: codecs • encodings

imported by: BlastPadControl.py • encodings

encodings.cp855 SourceModule

imports: codecs • encodings

imported by: BlastPadControl.py • encodings

encodings.cp856 SourceModule

imports: codecs • encodings

imported by: BlastPadControl.py • encodings

encodings.cp857 SourceModule

imports: codecs • encodings

imported by: BlastPadControl.py • encodings

encodings.cp858 SourceModule

imports: codecs • encodings

imported by: BlastPadControl.py • encodings

encodings.cp860 SourceModule

imports: codecs • encodings

imported by: BlastPadControl.py • encodings

encodings.cp861 SourceModule

imports: codecs • encodings

imported by: BlastPadControl.py • encodings

encodings.cp862 SourceModule

imports: codecs • encodings

imported by: BlastPadControl.py • encodings

encodings.cp863 SourceModule

imports: codecs • encodings

imported by: BlastPadControl.py • encodings

encodings.cp864 SourceModule

imports: codecs • encodings

imported by: BlastPadControl.py • encodings

encodings.cp865 SourceModule

imports: codecs • encodings

imported by: BlastPadControl.py • encodings

encodings.cp866 SourceModule

imports: codecs • encodings

imported by: BlastPadControl.py • encodings

encodings.cp869 SourceModule

imports: codecs • encodings

imported by: BlastPadControl.py • encodings

encodings.cp874 SourceModule

imports: codecs • encodings

imported by: BlastPadControl.py • encodings

encodings.cp875 SourceModule

imports: codecs • encodings

imported by: BlastPadControl.py • encodings

encodings.cp932 SourceModule

imports: _codecs_jp • _multibytecodec • codecs • encodings

imported by: BlastPadControl.py • encodings

encodings.cp949 SourceModule

imports: _codecs_kr • _multibytecodec • codecs • encodings

imported by: BlastPadControl.py • encodings

encodings.cp950 SourceModule

imports: _codecs_tw • _multibytecodec • codecs • encodings

imported by: BlastPadControl.py • encodings

encodings.euc_jis_2004 SourceModule

imports: _codecs_jp • _multibytecodec • codecs • encodings

imported by: BlastPadControl.py • encodings

encodings.euc_jisx0213 SourceModule

imports: _codecs_jp • _multibytecodec • codecs • encodings

imported by: BlastPadControl.py • encodings

encodings.euc_jp SourceModule

imports: _codecs_jp • _multibytecodec • codecs • encodings

imported by: BlastPadControl.py • encodings

encodings.euc_kr SourceModule

imports: _codecs_kr • _multibytecodec • codecs • encodings

imported by: BlastPadControl.py • encodings

encodings.gb18030 SourceModule

imports: _codecs_cn • _multibytecodec • codecs • encodings

imported by: BlastPadControl.py • encodings

encodings.gb2312 SourceModule

imports: _codecs_cn • _multibytecodec • codecs • encodings

imported by: BlastPadControl.py • encodings

encodings.gbk SourceModule

imports: _codecs_cn • _multibytecodec • codecs • encodings

imported by: BlastPadControl.py • encodings

encodings.hex_codec SourceModule

imports: binascii • codecs • encodings

imported by: BlastPadControl.py • encodings

encodings.hp_roman8 SourceModule

imports: codecs • encodings

imported by: BlastPadControl.py • encodings

encodings.hz SourceModule

imports: _codecs_cn • _multibytecodec • codecs • encodings

imported by: BlastPadControl.py • encodings

encodings.idna SourceModule

imports: codecs • encodings • re • stringprep • unicodedata

imported by: BlastPadControl.py • encodings

encodings.iso2022_jp SourceModule

imports: _codecs_iso2022 • _multibytecodec • codecs • encodings

imported by: BlastPadControl.py • encodings

encodings.iso2022_jp_1 SourceModule

imports: _codecs_iso2022 • _multibytecodec • codecs • encodings

imported by: BlastPadControl.py • encodings

encodings.iso2022_jp_2 SourceModule

imports: _codecs_iso2022 • _multibytecodec • codecs • encodings

imported by: BlastPadControl.py • encodings

encodings.iso2022_jp_2004 SourceModule

imports: _codecs_iso2022 • _multibytecodec • codecs • encodings

imported by: BlastPadControl.py • encodings

encodings.iso2022_jp_3 SourceModule

imports: _codecs_iso2022 • _multibytecodec • codecs • encodings

imported by: BlastPadControl.py • encodings

encodings.iso2022_jp_ext SourceModule

imports: _codecs_iso2022 • _multibytecodec • codecs • encodings

imported by: BlastPadControl.py • encodings

encodings.iso2022_kr SourceModule

imports: _codecs_iso2022 • _multibytecodec • codecs • encodings

imported by: BlastPadControl.py • encodings

encodings.iso8859_1 SourceModule

imports: codecs • encodings

imported by: BlastPadControl.py • encodings

encodings.iso8859_10 SourceModule

imports: codecs • encodings

imported by: BlastPadControl.py • encodings

encodings.iso8859_11 SourceModule

imports: codecs • encodings

imported by: BlastPadControl.py • encodings

encodings.iso8859_13 SourceModule

imports: codecs • encodings

imported by: BlastPadControl.py • encodings

encodings.iso8859_14 SourceModule

imports: codecs • encodings

imported by: BlastPadControl.py • encodings

encodings.iso8859_15 SourceModule

imports: codecs • encodings

imported by: BlastPadControl.py • encodings

encodings.iso8859_16 SourceModule

imports: codecs • encodings

imported by: BlastPadControl.py • encodings

encodings.iso8859_2 SourceModule

imports: codecs • encodings

imported by: BlastPadControl.py • encodings

encodings.iso8859_3 SourceModule

imports: codecs • encodings

imported by: BlastPadControl.py • encodings

encodings.iso8859_4 SourceModule

imports: codecs • encodings

imported by: BlastPadControl.py • encodings

encodings.iso8859_5 SourceModule

imports: codecs • encodings

imported by: BlastPadControl.py • encodings

encodings.iso8859_6 SourceModule

imports: codecs • encodings

imported by: BlastPadControl.py • encodings

encodings.iso8859_7 SourceModule

imports: codecs • encodings

imported by: BlastPadControl.py • encodings

encodings.iso8859_8 SourceModule

imports: codecs • encodings

imported by: BlastPadControl.py • encodings

encodings.iso8859_9 SourceModule

imports: codecs • encodings

imported by: BlastPadControl.py • encodings

encodings.johab SourceModule

imports: _codecs_kr • _multibytecodec • codecs • encodings

imported by: BlastPadControl.py • encodings

encodings.koi8_r SourceModule

imports: codecs • encodings

imported by: BlastPadControl.py • encodings

encodings.koi8_t SourceModule

imports: codecs • encodings

imported by: BlastPadControl.py • encodings

encodings.koi8_u SourceModule

imports: codecs • encodings

imported by: BlastPadControl.py • encodings

encodings.kz1048 SourceModule

imports: codecs • encodings

imported by: BlastPadControl.py • encodings

encodings.latin_1 SourceModule

imports: codecs • encodings

imported by: BlastPadControl.py • encodings

encodings.mac_arabic SourceModule

imports: codecs • encodings

imported by: BlastPadControl.py • encodings

encodings.mac_croatian SourceModule

imports: codecs • encodings

imported by: BlastPadControl.py • encodings

encodings.mac_cyrillic SourceModule

imports: codecs • encodings

imported by: BlastPadControl.py • encodings

encodings.mac_farsi SourceModule

imports: codecs • encodings

imported by: BlastPadControl.py • encodings

encodings.mac_greek SourceModule

imports: codecs • encodings

imported by: BlastPadControl.py • encodings

encodings.mac_iceland SourceModule

imports: codecs • encodings

imported by: BlastPadControl.py • encodings

encodings.mac_latin2 SourceModule

imports: codecs • encodings

imported by: BlastPadControl.py • encodings

encodings.mac_roman SourceModule

imports: codecs • encodings

imported by: BlastPadControl.py • encodings

encodings.mac_romanian SourceModule

imports: codecs • encodings

imported by: BlastPadControl.py • encodings

encodings.mac_turkish SourceModule

imports: codecs • encodings

imported by: BlastPadControl.py • encodings

encodings.mbcs SourceModule

imports: codecs • encodings

imported by: BlastPadControl.py • encodings

encodings.oem SourceModule

imports: codecs • encodings

imported by: BlastPadControl.py • encodings

encodings.palmos SourceModule

imports: codecs • encodings

imported by: BlastPadControl.py • encodings

encodings.ptcp154 SourceModule

imports: codecs • encodings

imported by: BlastPadControl.py • encodings

encodings.punycode SourceModule

imports: codecs • encodings

imported by: BlastPadControl.py • encodings

encodings.quopri_codec SourceModule

imports: codecs • encodings • io • quopri

imported by: BlastPadControl.py • encodings

encodings.raw_unicode_escape SourceModule

imports: codecs • encodings

imported by: BlastPadControl.py • encodings

encodings.rot_13 SourceModule

imports: codecs • encodings • sys

imported by: BlastPadControl.py • encodings

encodings.shift_jis SourceModule

imports: _codecs_jp • _multibytecodec • codecs • encodings

imported by: BlastPadControl.py • encodings

encodings.shift_jis_2004 SourceModule

imports: _codecs_jp • _multibytecodec • codecs • encodings

imported by: BlastPadControl.py • encodings

encodings.shift_jisx0213 SourceModule

imports: _codecs_jp • _multibytecodec • codecs • encodings

imported by: BlastPadControl.py • encodings

encodings.tis_620 SourceModule

imports: codecs • encodings

imported by: BlastPadControl.py • encodings

encodings.undefined SourceModule

imports: codecs • encodings

imported by: BlastPadControl.py • encodings

encodings.unicode_escape SourceModule

imports: codecs • encodings

imported by: BlastPadControl.py • encodings

encodings.utf_16 SourceModule

imports: codecs • encodings • sys

imported by: BlastPadControl.py • encodings

encodings.utf_16_be SourceModule

imports: codecs • encodings

imported by: BlastPadControl.py • encodings

encodings.utf_16_le SourceModule

imports: codecs • encodings

imported by: BlastPadControl.py • encodings

encodings.utf_32 SourceModule

imports: codecs • encodings • sys

imported by: BlastPadControl.py • encodings

encodings.utf_32_be SourceModule

imports: codecs • encodings

imported by: BlastPadControl.py • encodings

encodings.utf_32_le SourceModule

imports: codecs • encodings

imported by: BlastPadControl.py • encodings

encodings.utf_7 SourceModule

imports: codecs • encodings

imported by: BlastPadControl.py • encodings

encodings.utf_8 SourceModule

imports: codecs • encodings

imported by: BlastPadControl.py • encodings

encodings.utf_8_sig SourceModule

imports: codecs • encodings

imported by: BlastPadControl.py • encodings

encodings.uu_codec SourceModule

imports: binascii • codecs • encodings • io

imported by: BlastPadControl.py • encodings

encodings.zlib_codec SourceModule

imports: codecs • encodings • zlib

imported by: BlastPadControl.py • encodings

enum SourceModule

imports: sys • types • warnings

imported by: BlastPadControl.py • ast • asyncio.constants • http • inspect • plistlib • py_compile • re • signal • socket • ssl • tkinter

errno (builtin module)

imported by: asyncio.selector_events • asyncio.unix_events • asyncio.windows_events • distutils.dir_util • distutils.file_util • gettext • gzip • multiprocessing.forkserver • multiprocessing.queues • multiprocessing.shared_memory • pathlib • shutil • socket • ssl • subprocess • tempfile • test.support • xmlrpc.client

fnmatch SourceModule

imports: functools • itertools • os • posixpath • re

imported by: bdb • distutils.filelist • glob • pathlib • shutil • test.support • tracemalloc • unittest.loader • urllib.request

fractions SourceModule

imports: decimal • math • numbers • operator • re • sys

imported by: statistics

ftplib SourceModule

imports: netrc • re • socket • ssl • sys • warnings

imported by: urllib.request

functools SourceModule

imports: _functools • _thread • abc • collections • reprlib • types • typing • weakref

imported by: BlastPadControl.py • asyncio.base_events • asyncio.coroutines • asyncio.format_helpers • asyncio.selector_events • asyncio.tasks • asyncio.threads • concurrent.futures.process • configparser • contextlib • distutils.filelist • email._encoded_words • email.charset • fnmatch • http.server • importlib.metadata • importlib.util • inspect • linecache • locale • multiprocessing.reduction • multiprocessing.shared_memory • operator • pathlib • pickle • pkgutil • platform • re • signal • tempfile • test.support • test.support.testresult • threading • tracemalloc • types • typing • unittest.case • unittest.loader • unittest.result • unittest.signals

gc (builtin module)

imports: time

imported by: _posixsubprocess • test.support • weakref

genericpath SourceModule

imports: os • stat

imported by: ntpath • posixpath

getopt SourceModule

imports: gettext • os • sys

imported by: base64 • distutils.fancy_getopt • mimetypes • pdb • pydoc • quopri • webbrowser

getpass SourceModule

imports: contextlib • io • msvcrt • os • pwd • sys • termios • warnings

imported by: urllib.request

gettext SourceModule

imports: builtins • copy • errno • locale • os • re • struct • sys • warnings

imported by: argparse • getopt • optparse

glob SourceModule

imports: contextlib • fnmatch • os • re • sys

imported by: pdb • test.support • webbrowser

grp /Library/Frameworks/Python.framework/Versions/3.9/lib/python3.9/lib-dynload/grp.cpython-39-darwin.so

imported by: pathlib • shutil • subprocess • tarfile

gzip SourceModule

imports: _compression • argparse • builtins • errno • io • os • struct • sys • time • warnings • zlib

imported by: tarfile • test.support • xmlrpc.client

hashlib SourceModule

imports: _blake2 • _hashlib • _md5 • _sha1 • _sha256 • _sha3 • _sha512 • logging

imported by: hmac • random • urllib.request

heapq SourceModule

imports: _heapq

imported by: BlastPadControl.py • asyncio.base_events • asyncio.queues • collections • difflib • queue

hmac SourceModule

imports: _hashlib • _operator • hashlib • warnings

imported by: multiprocessing.connection • secrets

html Package

imports: html.entities • re

imported by: html.entities • http.server

html.entities SourceModule

imports: html

imported by: html

http Package

imports: enum

imported by: http.client • http.cookiejar • http.server

http.client SourceModule

imports: collections.abc • email.message • email.parser • http • io • re • socket • ssl • urllib.parse • warnings

imported by: http.cookiejar • http.server • urllib.request • xmlrpc.client

http.cookiejar SourceModule

imports: calendar • copy • datetime • http • http.client • io • logging • os • re • threading • time • traceback • urllib.parse • urllib.request • warnings

imported by: urllib.request

http.server SourceModule

imports: argparse • base64 • binascii • contextlib • copy • datetime • email.utils • functools • html • http • http.client • io • mimetypes • os • posixpath • pwd • select • shutil • socket • socketserver • subprocess • sys • time • urllib.parse

imported by: pydoc

importlib Package

imports: _frozen_importlib • _frozen_importlib_external • _imp • importlib • importlib._bootstrap • importlib._bootstrap_external • importlib.machinery • sys • types • warnings

imported by: importlib • importlib._bootstrap • importlib._bootstrap_external • importlib.abc • importlib.machinery • importlib.metadata • importlib.util • inspect • pkgutil • test.support

importlib._bootstrap SourceModule

imports: _frozen_importlib_external • importlib

imported by: importlib • importlib.abc • importlib.machinery • importlib.util • pydoc

importlib._bootstrap_external SourceModule

imports: _imp • _io • _warnings • importlib • importlib.metadata • marshal • nt • posix • sys • tokenize • winreg

imported by: importlib • importlib.abc • importlib.machinery • importlib.util • py_compile • pydoc

importlib.abc SourceModule

imports: _frozen_importlib • _frozen_importlib_external • abc • importlib • importlib._bootstrap • importlib._bootstrap_external • importlib.machinery • typing • warnings

imported by: importlib.metadata • importlib.util • zipimport

importlib.machinery SourceModule

imports: _imp • importlib • importlib._bootstrap • importlib._bootstrap_external

imported by: ctypes.util • importlib • importlib.abc • inspect • pkgutil • py_compile • pydoc • runpy

importlib.metadata SourceModule

imports: abc • collections • configparser • contextlib • csv • email • functools • importlib • importlib.abc • io • itertools • operator • os • pathlib • pep517 • posixpath • re • sys • zipfile

imported by: importlib._bootstrap_external

importlib.util SourceModule

imports: _imp • contextlib • functools • importlib • importlib._bootstrap • importlib._bootstrap_external • importlib.abc • sys • types • warnings

imported by: distutils.util • pkgutil • py_compile • pydoc • runpy • test.support • zipfile

inspect SourceModule

imports: abc • argparse • ast • builtins • collections • collections.abc • dis • enum • functools • importlib • importlib.machinery • itertools • linecache • operator • os • re • sys • token • tokenize • types • warnings

imported by: ast • asyncio.coroutines • asyncio.format_helpers • asyncio.tasks • bdb • doctest • pdb • pkgutil • pydoc • pyi_rth_inspect.py • unittest.async_case

io SourceModule

imports: _io • abc

imported by: BlastPadControl.py • _compression • asyncio.proactor_events • asyncio.unix_events • bz2 • configparser • csv • dis • distutils.text_file • doctest • email.feedparser • email.generator • email.iterators • email.message • email.parser • encodings.quopri_codec • encodings.uu_codec • getpass • gzip • http.client • http.cookiejar • http.server • importlib.metadata • lib2to3.patcomp • lib2to3.pgen2.driver • lib2to3.pytree • lib2to3.refactor • logging • lzma • multiprocessing.connection • multiprocessing.popen_forkserver • multiprocessing.popen_spawn_posix • multiprocessing.reduction • os • pathlib • pdb • pickle • plistlib • pprint • pydoc • quopri • runpy • shlex • socket • socketserver • subprocess • tarfile • tempfile • test.support • test.support.testresult • tokenize • unittest.result • urllib.request • xml.etree.ElementTree • xml.sax • xml.sax.saxutils • xmlrpc.client • zipfile • zipimport

itertools (builtin module)

imported by: _pydecimal • asyncio.base_events • asyncio.tasks • asyncio.unix_events • asyncio.windows_utils • calendar • collections • concurrent.futures.process • concurrent.futures.thread • configparser • ctypes.macholib.dyld • fnmatch • importlib.metadata • inspect • lib2to3.btm_matcher • lib2to3.refactor • multiprocessing.connection • multiprocessing.pool • multiprocessing.process • multiprocessing.util • pickle • platform • plistlib • random • reprlib • statistics • threading • tokenize • traceback • weakref • zipfile

java MissingModule

imported by: platform

json Package

imports: codecs • json.decoder • json.encoder • json.scanner

imported by: BlastPadControl.py • json.decoder • json.encoder • json.scanner

json.decoder SourceModule

imports: _json • json • json.scanner • re

imported by: _json • json

json.encoder SourceModule

imports: _json • json • re

imported by: json

json.scanner SourceModule

imports: _json • json • re

imported by: json • json.decoder

keyword SourceModule

imported by: BlastPadControl.py • collections

linecache SourceModule

imports: functools • os • sys • tokenize

imported by: BlastPadControl.py • asyncio.base_tasks • bdb • doctest • inspect • pdb • traceback • tracemalloc • warnings

locale SourceModule

imports: _bootlocale • _collections_abc • _locale • builtins • encodings • encodings.aliases • functools • os • re • sys • warnings

imported by: BlastPadControl.py • _bootlocale • _pydecimal • _strptime • calendar • gettext • test.support • xml.etree.ElementTree

logging Package

imports: atexit • collections.abc • io • os • pickle • re • string • sys • threading • time • traceback • warnings • weakref

imported by: asyncio.futures • asyncio.log • concurrent.futures._base • hashlib • http.cookiejar • lib2to3.btm_matcher • lib2to3.pgen2.driver • lib2to3.refactor • multiprocessing.util • unittest._log

lzma SourceModule

imports: _compression • _lzma • builtins • io • os

imported by: shutil • tarfile • test.support • zipfile

marshal (builtin module)

imported by: importlib._bootstrap_external • pkgutil • zipimport

math /Library/Frameworks/Python.framework/Versions/3.9/lib/python3.9/lib-dynload/math.cpython-39-darwin.so

imported by: _pydecimal • asyncio.windows_events • datetime • fractions • random • selectors • statistics

mimetypes SourceModule

imports: getopt • os • posixpath • sys • urllib.parse • winreg

imported by: http.server • urllib.request

mmap /Library/Frameworks/Python.framework/Versions/3.9/lib/python3.9/lib-dynload/mmap.cpython-39-darwin.so

imported by: multiprocessing.heap • multiprocessing.shared_memory

msvcrt MissingModule

imported by: asyncio.windows_events • asyncio.windows_utils • getpass • multiprocessing.popen_spawn_win32 • multiprocessing.spawn • subprocess • test.support

multiprocessing Package

imports: multiprocessing • multiprocessing.AuthenticationError • multiprocessing.BufferTooShort • multiprocessing.TimeoutError • multiprocessing.connection • multiprocessing.context • multiprocessing.forkserver • multiprocessing.get_context • multiprocessing.get_start_method • multiprocessing.pool • multiprocessing.process • multiprocessing.reduction • multiprocessing.resource_sharer • multiprocessing.resource_tracker • multiprocessing.set_start_method • multiprocessing.shared_memory • multiprocessing.spawn • multiprocessing.util • sys

imported by: concurrent.futures.process • lib2to3.refactor • multiprocessing • multiprocessing.connection • multiprocessing.context • multiprocessing.dummy • multiprocessing.forkserver • multiprocessing.heap • multiprocessing.managers • multiprocessing.pool • multiprocessing.popen_fork • multiprocessing.popen_forkserver • multiprocessing.popen_spawn_posix • multiprocessing.popen_spawn_win32 • multiprocessing.process • multiprocessing.queues • multiprocessing.reduction • multiprocessing.resource_sharer • multiprocessing.resource_tracker • multiprocessing.shared_memory • multiprocessing.sharedctypes • multiprocessing.spawn • multiprocessing.synchronize • multiprocessing.util • pyi_rth_multiprocessing.py

multiprocessing.AuthenticationError MissingModule

imported by: multiprocessing • multiprocessing.connection

multiprocessing.BufferTooShort MissingModule

imported by: multiprocessing • multiprocessing.connection

multiprocessing.TimeoutError MissingModule

imported by: multiprocessing • multiprocessing.pool

multiprocessing.connection SourceModule

imports: _multiprocessing • _winapi • hmac • io • itertools • multiprocessing • multiprocessing.AuthenticationError • multiprocessing.BufferTooShort • multiprocessing.context • multiprocessing.resource_sharer • multiprocessing.util • os • selectors • socket • struct • sys • tempfile • time • xmlrpc.client

imported by: concurrent.futures.process • multiprocessing • multiprocessing.context • multiprocessing.forkserver • multiprocessing.managers • multiprocessing.pool • multiprocessing.popen_fork • multiprocessing.popen_forkserver • multiprocessing.process • multiprocessing.queues • multiprocessing.resource_sharer

multiprocessing.context SourceModule

imports: multiprocessing • multiprocessing.connection • multiprocessing.forkserver • multiprocessing.managers • multiprocessing.pool • multiprocessing.popen_fork • multiprocessing.popen_forkserver • multiprocessing.popen_spawn_posix • multiprocessing.popen_spawn_win32 • multiprocessing.process • multiprocessing.queues • multiprocessing.reduction • multiprocessing.sharedctypes • multiprocessing.spawn • multiprocessing.synchronize • multiprocessing.util • os • sys • threading

imported by: multiprocessing • multiprocessing.connection • multiprocessing.forkserver • multiprocessing.heap • multiprocessing.managers • multiprocessing.popen_forkserver • multiprocessing.popen_spawn_posix • multiprocessing.popen_spawn_win32 • multiprocessing.process • multiprocessing.queues • multiprocessing.reduction • multiprocessing.resource_sharer • multiprocessing.sharedctypes • multiprocessing.spawn • multiprocessing.synchronize

multiprocessing.dummy Package

imports: array • multiprocessing • multiprocessing.dummy.connection • multiprocessing.pool • queue • sys • threading • weakref

imported by: multiprocessing.dummy.connection • multiprocessing.pool

multiprocessing.dummy.connection SourceModule

imports: multiprocessing.dummy • queue

imported by: multiprocessing.dummy

multiprocessing.forkserver SourceModule

imports: errno • multiprocessing • multiprocessing.connection • multiprocessing.context • multiprocessing.process • multiprocessing.resource_tracker • multiprocessing.spawn • multiprocessing.util • os • selectors • signal • socket • struct • sys • threading • warnings

imported by: multiprocessing • multiprocessing.context • multiprocessing.popen_forkserver • multiprocessing.util

multiprocessing.get_context MissingModule

imported by: multiprocessing • multiprocessing.managers • multiprocessing.pool • multiprocessing.sharedctypes

multiprocessing.get_start_method MissingModule

imported by: multiprocessing • multiprocessing.spawn

multiprocessing.heap SourceModule

imports: _winapi • bisect • collections • mmap • multiprocessing • multiprocessing.context • multiprocessing.util • os • sys • tempfile • threading

imported by: multiprocessing.sharedctypes • multiprocessing.synchronize

multiprocessing.managers SourceModule

imports: array • multiprocessing • multiprocessing.connection • multiprocessing.context • multiprocessing.get_context • multiprocessing.pool • multiprocessing.process • multiprocessing.resource_tracker • multiprocessing.shared_memory • multiprocessing.util • os • queue • signal • sys • threading • time • traceback • types

imported by: multiprocessing.context

multiprocessing.pool SourceModule

imports: collections • itertools • multiprocessing • multiprocessing.TimeoutError • multiprocessing.connection • multiprocessing.dummy • multiprocessing.get_context • multiprocessing.util • os • queue • threading • time • traceback • types • warnings

imported by: multiprocessing • multiprocessing.context • multiprocessing.dummy • multiprocessing.managers

multiprocessing.popen_fork SourceModule

imports: multiprocessing • multiprocessing.connection • multiprocessing.util • os • signal

imported by: multiprocessing.context • multiprocessing.popen_forkserver • multiprocessing.popen_spawn_posix • pyi_rth_multiprocessing.py

multiprocessing.popen_forkserver SourceModule

imports: io • multiprocessing • multiprocessing.connection • multiprocessing.context • multiprocessing.forkserver • multiprocessing.popen_fork • multiprocessing.spawn • multiprocessing.util • os

imported by: multiprocessing.context

multiprocessing.popen_spawn_posix SourceModule

imports: io • multiprocessing • multiprocessing.context • multiprocessing.popen_fork • multiprocessing.resource_tracker • multiprocessing.spawn • multiprocessing.util • os

imported by: multiprocessing.context • pyi_rth_multiprocessing.py

multiprocessing.popen_spawn_win32 SourceModule

imports: _winapi • msvcrt • multiprocessing • multiprocessing.context • multiprocessing.spawn • multiprocessing.util • os • signal • sys

imported by: multiprocessing.context • pyi_rth_multiprocessing.py

multiprocessing.process SourceModule

imports: _weakrefset • itertools • multiprocessing • multiprocessing.connection • multiprocessing.context • multiprocessing.util • os • signal • sys • threading • traceback

imported by: multiprocessing • multiprocessing.context • multiprocessing.forkserver • multiprocessing.managers • multiprocessing.resource_sharer • multiprocessing.spawn • multiprocessing.synchronize • multiprocessing.util

multiprocessing.queues SourceModule

imports: _multiprocessing • collections • errno • multiprocessing • multiprocessing.connection • multiprocessing.context • multiprocessing.synchronize • multiprocessing.util • os • queue • sys • threading • time • traceback • types • weakref

imported by: concurrent.futures.process • multiprocessing.context

multiprocessing.reduction SourceModule

imports: _winapi • abc • array • copyreg • functools • io • multiprocessing • multiprocessing.context • multiprocessing.resource_sharer • os • pickle • socket • sys

imported by: multiprocessing • multiprocessing.context

multiprocessing.resource_sharer SourceModule

imports: multiprocessing • multiprocessing.connection • multiprocessing.context • multiprocessing.process • multiprocessing.util • os • signal • socket • sys • threading

imported by: multiprocessing • multiprocessing.connection • multiprocessing.reduction

multiprocessing.resource_tracker SourceModule

imports: _multiprocessing • _posixshmem • multiprocessing • multiprocessing.spawn • multiprocessing.util • os • signal • sys • threading • warnings

imported by: multiprocessing • multiprocessing.forkserver • multiprocessing.managers • multiprocessing.popen_spawn_posix • multiprocessing.shared_memory • multiprocessing.spawn • multiprocessing.synchronize • multiprocessing.util

multiprocessing.set_start_method MissingModule

imported by: multiprocessing • multiprocessing.spawn

multiprocessing.shared_memory SourceModule

imports: _posixshmem • _winapi • errno • functools • mmap • multiprocessing • multiprocessing.resource_tracker • os • secrets • struct • types

imported by: multiprocessing • multiprocessing.managers

multiprocessing.sharedctypes SourceModule

imports: ctypes • multiprocessing • multiprocessing.context • multiprocessing.get_context • multiprocessing.heap • weakref

imported by: multiprocessing.context

multiprocessing.spawn SourceModule

imports: _winapi • msvcrt • multiprocessing • multiprocessing.context • multiprocessing.get_start_method • multiprocessing.process • multiprocessing.resource_tracker • multiprocessing.set_start_method • multiprocessing.util • os • runpy • sys • types

imported by: multiprocessing • multiprocessing.context • multiprocessing.forkserver • multiprocessing.popen_forkserver • multiprocessing.popen_spawn_posix • multiprocessing.popen_spawn_win32 • multiprocessing.resource_tracker • pyi_rth_multiprocessing.py

multiprocessing.synchronize SourceModule

imports: _multiprocessing • multiprocessing • multiprocessing.context • multiprocessing.heap • multiprocessing.process • multiprocessing.resource_tracker • multiprocessing.util • struct • sys • tempfile • threading • time

imported by: multiprocessing.context • multiprocessing.queues

multiprocessing.util SourceModule

imports: _posixsubprocess • atexit • itertools • logging • multiprocessing • multiprocessing.forkserver • multiprocessing.process • multiprocessing.resource_tracker • os • shutil • subprocess • sys • tempfile • threading • traceback • weakref

imported by: multiprocessing • multiprocessing.connection • multiprocessing.context • multiprocessing.forkserver • multiprocessing.heap • multiprocessing.managers • multiprocessing.pool • multiprocessing.popen_fork • multiprocessing.popen_forkserver • multiprocessing.popen_spawn_posix • multiprocessing.popen_spawn_win32 • multiprocessing.process • multiprocessing.queues • multiprocessing.resource_sharer • multiprocessing.resource_tracker • multiprocessing.spawn • multiprocessing.synchronize

netrc SourceModule

imports: os • pwd • shlex • stat

imported by: ftplib

nt MissingModule

imported by: ctypes • importlib._bootstrap_external • ntpath • os • pathlib • shutil

ntpath SourceModule

imports: genericpath • nt • os • stat • string • sys

imported by: os • pathlib

nturl2path SourceModule

imports: string • urllib.parse

imported by: urllib.request

numbers SourceModule

imports: abc

imported by: _pydecimal • fractions • statistics

opcode SourceModule

imports: _opcode

imported by: dis

operator SourceModule

imports: _operator • builtins • functools

imported by: BlastPadControl.py • collections • email._header_value_parser • fractions • importlib.metadata • inspect • lib2to3.refactor • pathlib • statistics • typing

optparse SourceModule

imports: gettext • os • sys • textwrap

imported by: uu

org MissingModule

imported by: pickle

os SourceModule

imports: _collections_abc • abc • io • nt • ntpath • posix • posixpath • posixpath • stat • subprocess • sys • warnings

imported by: BlastPadControl.py • _bootsubprocess • _osx_support • argparse • asyncio.base_events • asyncio.coroutines • asyncio.events • asyncio.proactor_events • asyncio.unix_events • asyncio.windows_utils • bdb • bz2 • concurrent.futures.process • concurrent.futures.thread • configparser • ctypes • ctypes._aix • ctypes.macholib.dyld • ctypes.util • distutils.ccompiler • distutils.debug • distutils.dep_util • distutils.dir_util • distutils.file_util • distutils.filelist • distutils.spawn • distutils.sysconfig • distutils.util • doctest • email.utils • fnmatch • genericpath • getopt • getpass • gettext • glob • gzip • http.cookiejar • http.server • importlib.metadata • inspect • lib2to3.pgen2.driver • lib2to3.pygram • lib2to3.refactor • linecache • locale • logging • lzma • mimetypes • multiprocessing.connection • multiprocessing.context • multiprocessing.forkserver • multiprocessing.heap • multiprocessing.managers • multiprocessing.pool • multiprocessing.popen_fork • multiprocessing.popen_forkserver • multiprocessing.popen_spawn_posix • multiprocessing.popen_spawn_win32 • multiprocessing.process • multiprocessing.queues • multiprocessing.reduction • multiprocessing.resource_sharer • multiprocessing.resource_tracker • multiprocessing.shared_memory • multiprocessing.spawn • multiprocessing.util • netrc • ntpath • optparse • pathlib • pdb • pkgutil • platform • plistlib • posixpath • posixpath • py_compile • pydoc • pyi_rth_inspect.py • pyi_rth_multiprocessing.py • pyi_rth_pkgutil.py • pyi_rth_pyqt5.py • random • runpy • shlex • shutil • socket • socketserver • ssl • subprocess • sysconfig • tarfile • tempfile • test.support • threading • tkinter • unittest.loader • unittest.main • urllib.request • uu • webbrowser • xml.sax • xml.sax.saxutils • zipfile • zipimport

pathlib SourceModule

imports: _collections_abc • errno • fnmatch • functools • grp • io • nt • ntpath • operator • os • posixpath • pwd • re • stat • sys • urllib.parse

imported by: importlib.metadata • zipimport

pdb SourceModule

imports: bdb • cmd • code • dis • getopt • glob • inspect • io • linecache • os • pdb • pprint • pydoc • re • readline • runpy • shlex • signal • sys • tokenize • traceback

imported by: doctest • pdb

pep517 MissingModule

imported by: importlib.metadata

pickle SourceModule

imports: _compat_pickle • _pickle • codecs • copyreg • doctest • functools • io • itertools • org • pprint • re • struct • sys • types

imported by: lib2to3.pgen2.grammar • logging • multiprocessing.reduction • tracemalloc

pkgutil SourceModule

imports: collections • functools • importlib • importlib.machinery • importlib.util • inspect • marshal • os • posixpath • re • sys • types • warnings • zipimport

imported by: lib2to3.pgen2.driver • lib2to3.refactor • pydoc • pyi_rth_pkgutil.py • runpy

platform SourceModule

imports: 'java.lang' • _winreg • collections • functools • itertools • java • os • plistlib • re • socket • struct • subprocess • sys • vms_lib • winreg

imported by: pydoc • test.support

plistlib SourceModule

imports: binascii • codecs • datetime • enum • io • itertools • os • re • struct • xml.parsers.expat

imported by: platform

posix (builtin module)

imports: resource

imported by: importlib._bootstrap_external • os • shutil

posixpath AliasNode

imports: os • posixpath

imported by: distutils.file_util • os • pkgutil • py_compile • sysconfig • tracemalloc • unittest • unittest.util

posixpath SourceModule

imports: genericpath • os • pwd • re • stat • sys

imported by: fnmatch • http.server • importlib.metadata • mimetypes • os • pathlib • posixpath • urllib.request • zipfile

pprint SourceModule

imports: collections • io • re • sys • time • types

imported by: BlastPadControl.py • lib2to3.pgen2.grammar • pdb • pickle • sysconfig • unittest.case

pwd (builtin module)

imported by: distutils.util • getpass • http.server • netrc • pathlib • posixpath • shutil • subprocess • tarfile • webbrowser

py_compile SourceModule

imports: enum • importlib._bootstrap_external • importlib.machinery • importlib.util • os • posixpath • sys • traceback

imported by: distutils.util • zipfile

pydoc SourceModule

imports: builtins • collections • email.message • getopt • http.server • importlib._bootstrap • importlib._bootstrap_external • importlib.machinery • importlib.util • inspect • io • os • pkgutil • platform • pydoc_data.topics • re • reprlib • select • subprocess • sys • sysconfig • tempfile • textwrap • threading • time • tokenize • traceback • tty • urllib.parse • warnings • webbrowser

imported by: pdb

pydoc_data Package

imported by: pydoc_data.topics

pydoc_data.topics SourceModule

imports: pydoc_data

imported by: pydoc

pyexpat /Library/Frameworks/Python.framework/Versions/3.9/lib/python3.9/lib-dynload/pyexpat.cpython-39-darwin.so

imported by: _elementtree • xml.etree.ElementTree • xml.parsers.expat

pyimod03_importers MissingModule

imported by: pyi_rth_pkgutil.py

queue SourceModule

imports: _queue • collections • heapq • threading • time • types

imported by: concurrent.futures.process • concurrent.futures.thread • multiprocessing.dummy • multiprocessing.dummy.connection • multiprocessing.managers • multiprocessing.pool • multiprocessing.queues

quopri SourceModule

imports: binascii • getopt • io • sys

imported by: email.encoders • email.message • encodings.quopri_codec

random SourceModule

imports: _collections_abc • _random • _sha512 • bisect • hashlib • itertools • math • os • statistics • time • warnings

imported by: email.generator • email.utils • secrets • statistics • tempfile

re SourceModule

imports: _locale • copyreg • enum • functools • sre_compile • sre_constants • sre_parse

imported by: BlastPadControl.py • _osx_support • _pydecimal • _sre • _strptime • argparse • base64 • configparser • csv • ctypes._aix • ctypes.macholib.dylib • ctypes.macholib.framework • ctypes.util • difflib • distutils.ccompiler • distutils.fancy_getopt • distutils.filelist • distutils.sysconfig • distutils.util • doctest • email._encoded_words • email._header_value_parser • email.feedparser • email.generator • email.header • email.message • email.policy • email.quoprimime • email.utils • encodings.idna • fnmatch • fractions • ftplib • gettext • glob • html • http.client • http.cookiejar • importlib.metadata • inspect • json.decoder • json.encoder • json.scanner • lib2to3.pgen2.literals • lib2to3.pgen2.tokenize • locale • logging • pathlib • pdb • pickle • pkgutil • platform • plistlib • posixpath • pprint • pydoc • shlex • string • sysconfig • tarfile • test.support • textwrap • tkinter • tokenize • typing • unittest.case • unittest.loader • urllib.parse • urllib.request • warnings • xml.etree.ElementPath • xml.etree.ElementTree

readline /Library/Frameworks/Python.framework/Versions/3.9/lib/python3.9/lib-dynload/readline.cpython-39-darwin.so

imported by: cmd • code • pdb

reprlib SourceModule

imports: _thread • builtins • itertools

imported by: BlastPadControl.py • asyncio.base_futures • asyncio.format_helpers • bdb • collections • functools • pydoc

resource /Library/Frameworks/Python.framework/Versions/3.9/lib/python3.9/lib-dynload/resource.cpython-39-darwin.so

imported by: posix • test.support

runpy SourceModule

imports: importlib.machinery • importlib.util • io • os • pkgutil • sys • types • warnings

imported by: multiprocessing.spawn • pdb

secrets SourceModule

imports: base64 • binascii • hmac • random

imported by: multiprocessing.shared_memory

select /Library/Frameworks/Python.framework/Versions/3.9/lib/python3.9/lib-dynload/select.cpython-39-darwin.so

imported by: http.server • pydoc • selectors • subprocess

selectors SourceModule

imports: abc • collections • collections.abc • math • select • sys

imported by: asyncio.selector_events • asyncio.unix_events • multiprocessing.connection • multiprocessing.forkserver • socket • socketserver • subprocess

shlex SourceModule

imports: collections • io • os • re • sys • warnings

imported by: netrc • pdb • webbrowser

shutil SourceModule

imports: bz2 • collections • errno • fnmatch • grp • lzma • nt • os • posix • pwd • stat • sys • tarfile • zipfile • zlib

imported by: argparse • ctypes.util • http.server • multiprocessing.util • tarfile • tempfile • test.support • webbrowser • zipfile

signal SourceModule

imports: _signal • enum • functools

imported by: asyncio.proactor_events • asyncio.unix_events • multiprocessing.forkserver • multiprocessing.managers • multiprocessing.popen_fork • multiprocessing.popen_spawn_win32 • multiprocessing.process • multiprocessing.resource_sharer • multiprocessing.resource_tracker • pdb • subprocess • test.support • unittest.signals

socket SourceModule

imports: _socket • array • enum • errno • io • os • selectors • sys

imported by: _ssl • asyncio.base_events • asyncio.events • asyncio.proactor_events • asyncio.selector_events • asyncio.streams • asyncio.trsock • asyncio.unix_events • asyncio.windows_events • email.utils • ftplib • http.client • http.server • multiprocessing.connection • multiprocessing.forkserver • multiprocessing.reduction • multiprocessing.resource_sharer • platform • socketserver • ssl • urllib.request • webbrowser

socketserver SourceModule

imports: io • os • selectors • socket • sys • threading • time • traceback

imported by: http.server

sre_compile SourceModule

imports: _sre • sre_constants • sre_parse • sys

imported by: BlastPadControl.py • re

sre_constants SourceModule

imports: _sre

imported by: BlastPadControl.py • re • sre_compile • sre_parse

sre_parse SourceModule

imports: sre_constants • unicodedata • warnings

imported by: BlastPadControl.py • re • sre_compile

ssl SourceModule

imports: _ssl • base64 • calendar • collections • enum • errno • os • socket • sys • time • warnings

imported by: asyncio.base_events • asyncio.selector_events • asyncio.sslproto • ftplib • http.client • urllib.request

stat SourceModule

imports: _stat

imported by: asyncio.base_events • asyncio.unix_events • distutils.dep_util • distutils.file_util • genericpath • netrc • ntpath • os • pathlib • posixpath • shutil • tarfile • test.support • zipfile

statistics SourceModule

imports: _statistics • bisect • collections • decimal • fractions • itertools • math • numbers • operator • random

imported by: random

string SourceModule

imports: _string • collections • re

imported by: cmd • distutils.fancy_getopt • distutils.util • email._encoded_words • email._header_value_parser • email.quoprimime • lib2to3.pgen2.tokenize • logging • ntpath • nturl2path • urllib.request

stringprep SourceModule

imports: unicodedata

imported by: encodings.idna

struct SourceModule

imports: _struct

imported by: asyncio.windows_events • base64 • ctypes • ctypes.util • gettext • gzip • multiprocessing.connection • multiprocessing.forkserver • multiprocessing.shared_memory • multiprocessing.synchronize • pickle • platform • plistlib • tarfile • test.support • zipfile

subprocess SourceModule

imports: _posixsubprocess • _winapi • builtins • contextlib • errno • grp • io • msvcrt • os • pwd • select • selectors • signal • sys • threading • time • types • warnings

imported by: _aix_support • asyncio.base_events • asyncio.base_subprocess • asyncio.events • asyncio.subprocess • asyncio.unix_events • asyncio.windows_utils • ctypes._aix • ctypes.util • distutils.spawn • distutils.util • http.server • multiprocessing.util • os • platform • pydoc • pyi_rth_multiprocessing.py • test.support • webbrowser

sys (builtin module)

imported by: BlastPadControl.py • _aix_support • _bootlocale • _collections_abc • _osx_support • _pydecimal • argparse • ast • asyncio • asyncio.base_events • asyncio.coroutines • asyncio.events • asyncio.format_helpers • asyncio.futures • asyncio.streams • asyncio.unix_events • asyncio.windows_utils • base64 • bdb • calendar • cmd • code • codecs • collections • concurrent.futures.process • configparser • contextlib • ctypes • ctypes._aix • ctypes._endian • ctypes.util • datetime • dis • distutils • distutils.ccompiler • distutils.fancy_getopt • distutils.log • distutils.spawn • distutils.sysconfig • distutils.text_file • distutils.util • doctest • email._header_value_parser • email.generator • email.iterators • email.policy • encodings • encodings.rot_13 • encodings.utf_16 • encodings.utf_32 • enum • fractions • ftplib • getopt • getpass • gettext • glob • gzip • http.server • importlib • importlib._bootstrap_external • importlib.metadata • importlib.util • inspect • lib2to3.pgen2.driver • lib2to3.pgen2.tokenize • lib2to3.pytree • lib2to3.refactor • linecache • locale • logging • mimetypes • multiprocessing • multiprocessing.connection • multiprocessing.context • multiprocessing.dummy • multiprocessing.forkserver • multiprocessing.heap • multiprocessing.managers • multiprocessing.popen_spawn_win32 • multiprocessing.process • multiprocessing.queues • multiprocessing.reduction • multiprocessing.resource_sharer • multiprocessing.resource_tracker • multiprocessing.spawn • multiprocessing.synchronize • multiprocessing.util • ntpath • optparse • os • pathlib • pdb • pickle • pkgutil • platform • posixpath • pprint • py_compile • pydoc • pyi_rth_inspect.py • pyi_rth_multiprocessing.py • pyi_rth_pkgutil.py • pyi_rth_pyqt5.py • quopri • runpy • selectors • shlex • shutil • socket • socketserver • sre_compile • ssl • subprocess • sysconfig • tarfile • tempfile • test.support • test.support.testresult • threading • tkinter • tokenize • traceback • types • typing • unittest.case • unittest.loader • unittest.main • unittest.result • unittest.runner • unittest.suite • urllib.parse • urllib.request • uu • warnings • weakref • webbrowser • xml.etree.ElementTree • xml.parsers.expat • xml.sax • xml.sax._exceptions • xml.sax.expatreader • xml.sax.saxutils • xmlrpc.client • zipfile • zipimport

sysconfig SourceModule

imports: _aix_support • _imp • _osx_support • _sysconfigdata__darwin_darwin • os • posixpath • pprint • re • sys • types • warnings

imported by: _aix_support • pydoc • test.support

tarfile SourceModule

imports: argparse • builtins • bz2 • copy • grp • gzip • io • lzma • os • pwd • re • shutil • stat • struct • sys • time • zlib

imported by: shutil

tempfile SourceModule

imports: _thread • errno • functools • io • os • random • shutil • sys • types • warnings • weakref

imported by: _osx_support • asyncio.windows_utils • ctypes.util • distutils.ccompiler • distutils.util • multiprocessing.connection • multiprocessing.heap • multiprocessing.synchronize • multiprocessing.util • pydoc • test.support • urllib.request • urllib.response • webbrowser

termios /Library/Frameworks/Python.framework/Versions/3.9/lib/python3.9/lib-dynload/termios.cpython-39-darwin.so

imported by: getpass • tty

textwrap SourceModule

imports: re

imported by: argparse • optparse • pydoc

threading SourceModule

imports: _collections • _thread • _threading_local • _weakrefset • collections • functools • itertools • os • sys • time • traceback

imported by: _threading_local • asyncio.base_events • asyncio.events • asyncio.proactor_events • asyncio.unix_events • bz2 • concurrent.futures._base • concurrent.futures.process • concurrent.futures.thread • http.cookiejar • logging • multiprocessing.context • multiprocessing.dummy • multiprocessing.forkserver • multiprocessing.heap • multiprocessing.managers • multiprocessing.pool • multiprocessing.process • multiprocessing.queues • multiprocessing.resource_sharer • multiprocessing.resource_tracker • multiprocessing.synchronize • multiprocessing.util • pydoc • queue • socketserver • subprocess • test.support • webbrowser • zipfile

time (builtin module)

imports: _strptime

imported by: _datetime • _strptime • asyncio.base_events • asyncio.windows_events • concurrent.futures._base • datetime • email._parseaddr • email.generator • email.utils • gc • gzip • http.cookiejar • http.server • logging • multiprocessing.connection • multiprocessing.managers • multiprocessing.pool • multiprocessing.queues • multiprocessing.synchronize • pprint • pydoc • queue • random • socketserver • ssl • subprocess • tarfile • test.support • test.support.testresult • threading • unittest.runner • urllib.request • xmlrpc.client • zipfile • zipimport

token SourceModule

imported by: inspect • tokenize

tokenize SourceModule

imports: argparse • builtins • codecs • collections • io • itertools • re • sys • token

imported by: importlib._bootstrap_external • inspect • linecache • pdb • pydoc

traceback SourceModule

imports: collections • itertools • linecache • sys

imported by: BlastPadControl.py • asyncio.base_events • asyncio.base_tasks • asyncio.coroutines • asyncio.format_helpers • code • concurrent.futures.process • doctest • http.cookiejar • logging • multiprocessing.managers • multiprocessing.pool • multiprocessing.process • multiprocessing.queues • multiprocessing.util • pdb • py_compile • pydoc • socketserver • test.support.testresult • threading • tkinter • unittest.case • unittest.loader • unittest.result • warnings

tracemalloc SourceModule

imports: _tracemalloc • collections.abc • fnmatch • functools • linecache • pickle • posixpath

imported by: test.support • warnings

tty SourceModule

imports: termios

imported by: pydoc

types SourceModule

imports: _collections_abc • functools • sys

imported by: BlastPadControl.py • _weakrefset • asyncio.coroutines • asyncio.tasks • concurrent.futures._base • concurrent.futures.thread • contextlib • copy • ctypes • difflib • dis • email.headerregistry • enum • functools • importlib • importlib.util • inspect • multiprocessing.managers • multiprocessing.pool • multiprocessing.queues • multiprocessing.shared_memory • multiprocessing.spawn • pickle • pkgutil • pprint • queue • runpy • subprocess • sysconfig • tempfile • test.support • tkinter • typing • unittest.case • unittest.loader • urllib.parse

typing SourceModule

imports: abc • collections • collections.abc • contextlib • functools • operator • re • sys • types

imported by: asyncio.staggered • functools • importlib.abc

unicodedata /Library/Frameworks/Python.framework/Versions/3.9/lib/python3.9/lib-dynload/unicodedata.cpython-39-darwin.so

imported by: encodings.idna • sre_parse • stringprep • test.support • urllib.parse

unittest Package

imports: posixpath • unittest • unittest.async_case • unittest.case • unittest.loader • unittest.main • unittest.result • unittest.runner • unittest.signals • unittest.suite • unittest.util

imported by: doctest • test.support • test.support.testresult • unittest • unittest._log • unittest.async_case • unittest.case • unittest.loader • unittest.main • unittest.result • unittest.runner • unittest.signals • unittest.suite • unittest.util

unittest._log SourceModule

imports: collections • logging • unittest • unittest.case

imported by: unittest.case

unittest.async_case SourceModule

imports: asyncio • inspect • unittest • unittest.case

imported by: unittest

unittest.case SourceModule

imports: collections • contextlib • difflib • functools • pprint • re • sys • traceback • types • unittest • unittest._log • unittest.result • unittest.util • warnings

imported by: unittest • unittest._log • unittest.async_case • unittest.loader • unittest.suite

unittest.loader SourceModule

imports: fnmatch • functools • os • re • sys • traceback • types • unittest • unittest.case • unittest.suite • unittest.util • warnings

imported by: unittest • unittest.main

unittest.main SourceModule

imports: argparse • os • sys • unittest • unittest.loader • unittest.runner • unittest.signals

imported by: unittest

unittest.result SourceModule

imports: functools • io • sys • traceback • unittest • unittest.util

imported by: unittest • unittest.case • unittest.runner

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

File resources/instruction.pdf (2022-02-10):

Default
–––––––––––––
e1:Numbers
e2:Up/Down

## Encoder Basics

In the next chapter we will talk more about Presets and how to set them up together with the Key and Encoder Actions. For now let’s focus on the behaviour of the latter.

Changing the Encoder Actions:
Push the knob like a button.
You can see on the display that encoder changed it’s title and therefore it changed its behaviour. Each Preset has its own set of “behaviours” that can be assigned to eighter Encoder 1 or Encoder 2 (see chapter Creating and editing Presets to learn how to create those behaviours).
There are two types of Encoder Actions:
- “Left/Right” Encoder Action
In this action you have assigned two keystrokes to the encoder: one to the counterclockwise and the other one to the clockwise movements.
Good example is the “Up/Down” action. Left movement performs “UP ARROW” keystroke, while right movement performs “DOWN ARROW” keystroke. Test it, for example, in some text editor. You will see that the cursor behaves in a similar way as the arrow buttons.
- “Carousel” Encoder Action
“Numbers” is a good example of a carousel action. In this action when you rotate the knob clockwise, it will execute numerical keystroke. With every step the keystroke will represent incremented digit starting from 0 (zero) until it will reach the number 9. After this, the counting will reset to 0. If you’ll rotate the knob counterclockwise, the operation will work almost the same. Except
this time, instead of incrementing, it will
decrement digits.

# Creating and editing Presets

Preset is a singular set of instructions, which determines
what keystroke sequence will be triggered by your keys or encoders. You can store almost as many presets on your BlastPad as you want.

Maximum number of actions in the Preset:
Each Preset has actions assigned to the keys, which max number in the preset is equal to the number of the buttons in BLASTPad‘s keyboard layout (23 – excluding the special lonely key on the right side of the device). Besides Key Actions, each preset can have Encoder Actions. Number of those is in theory limitless. You can switch between all of Preset‘s Encoder Actions with just two physical encoders.

## BlastPadControl app MacOS

(Currently in beta pre-release version)

Opening the app
Download the zip file using QR code on the end of this instruction.
Or go to the main GitHub page of this project
( https://github.com/RafalBuchner/blastpad ) and look for the link in the download section of the documentation.

# Instruction

# Layout

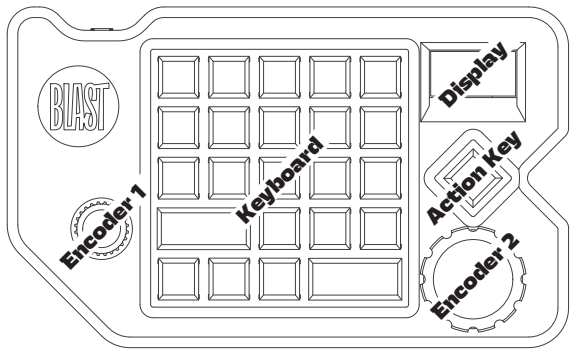
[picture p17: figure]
Encoder 1; Encoder 2; Keyboard; Display; Action Key

Keyborad’s layout was designed to resamble the most left 5 columns of a standard keyborad with the exclusion of the top row (which usually contains all the F keys together with ESC key ). All of the keys are programmable, which means that with the help of a small desktop app you will be able to change behaviour of each key by assigning keystroke combinations to all of them. Additionally BLASTPad has two rotary encoders, which can also trigger some keystroke actions.

# The First Run

1. Connect your BLASTPad to your computer via USB MICRO B cable. New usb storage device called BLASTPAD should appear. We will talk about
it more later.
2. Wait until BLAST logo disappears.
3. You should see the similar data on the display:

Default
–––––––––––––––––––
e1:Numbers
e2:Up/Down
- “Default”
is a title of currently active Preset.
- “Numbers”
is a title of an Encoder Action currently assigned to the Encoder 1
- “Up/Down”
is a title of an Encoder Action currently assigned to the Encoder 2

# Pad

## programmable keyboard

## Creating “Left/Right” Encoder Action

To create a “Left/Right” Encoder Action you have to assign 2 hotkeys to the encoder. One in the column “hotkey 1” and the otherone in the column “hotkey 2”.
The first one will be triggered when you rotate physical encoder counterclockwise. The second, whenever you rotate the same encoder in clockwise direction.

## Creating “Carousel” Encoder Action

To create a “Carousel” Encoder Action you have to assign any number of hotkeys, except 2.
If you want to have additional hotkey slots created, hit “add hotkey” button. You can add as many as you want.

## Windows

( It is currently under construction.
Beta version is coming very soon. )

## Saving presets onto the device

You save Presets as separate files with *.json extension.

Press Save button to create a Preset file. In order to save preset on your BLASTPad find the usb device with the same name and save the Preset into "Configs" folder. The name of the file will be used as a Preset Title on the BlastPad's display, so name it accordingly to your needs.

## Changing the active Presets on

the BlastPad device.

If you have more than one Presets you will be able to swich between the presets whenever you like!

It is super easy. Hold Action Key (the lonley key on the right side of the device). You will enter the Preset Selection menu. Now, rotate your Encoder 1 while holding the key. This way you will switch between the Presets.

Download App for MacOS

Inside the unzipped folder you will find BlastPadControl executable file. Double click on it. The window like one below should appear:

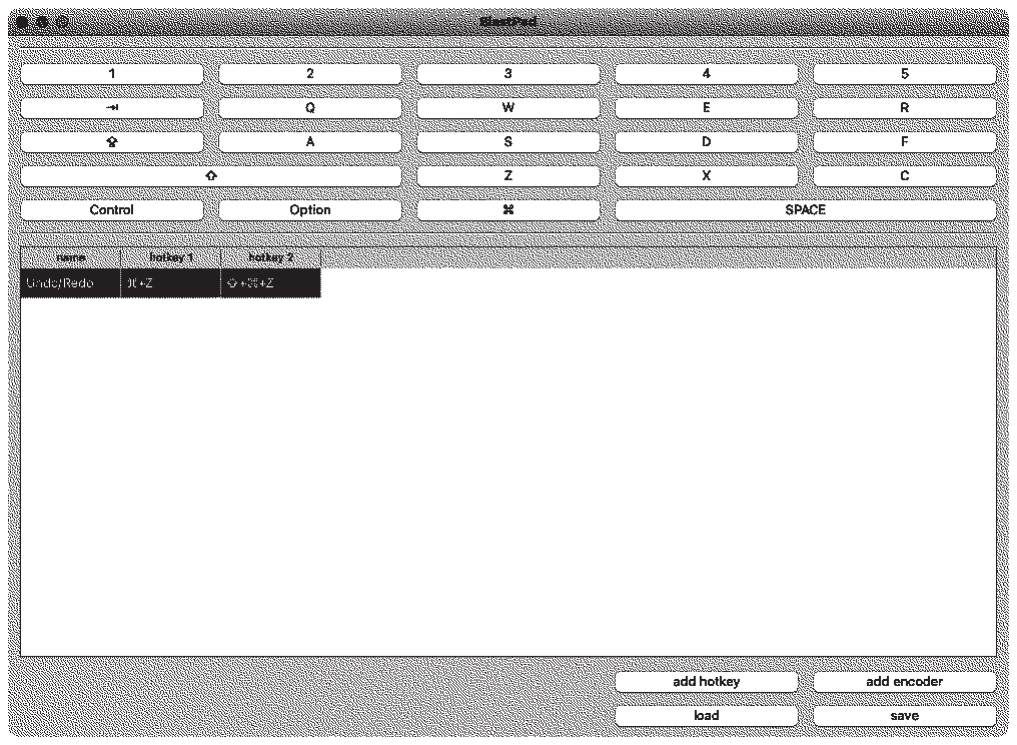
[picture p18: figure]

This is the Preset Editor. It is divided into two sections. One is responsible for controling the Key Actions. The other one for creating and editing the Encoder Actions.

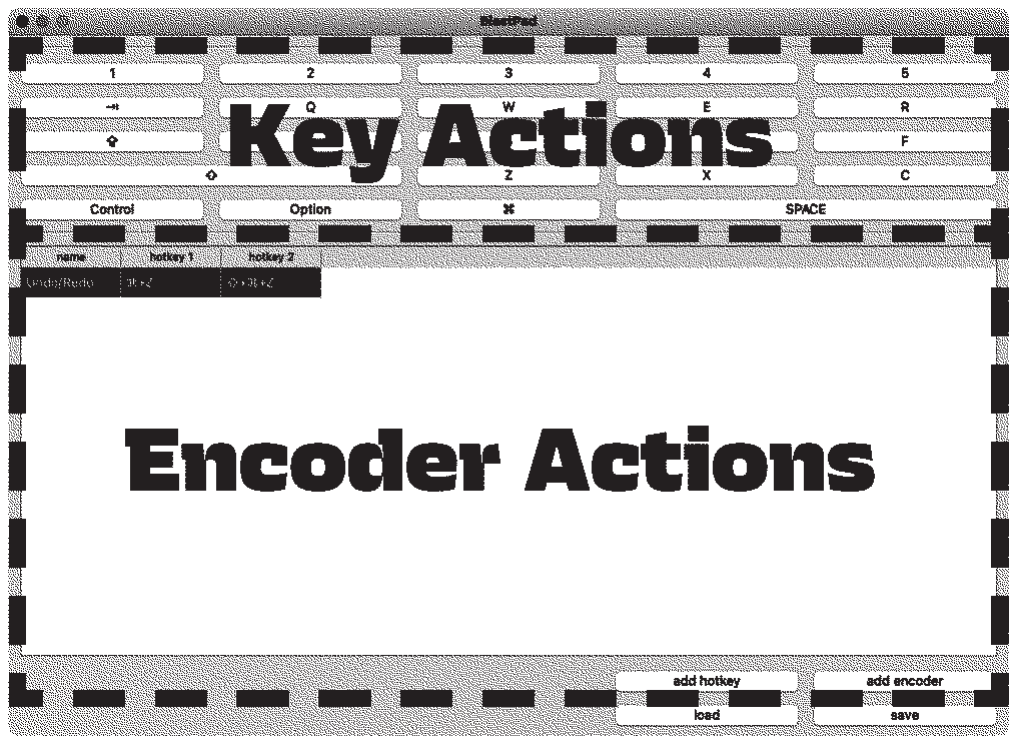
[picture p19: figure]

## Key Actions Section

The Key Actions Section‘s buttons recreates the BlastPad‘s keyboard layout. If you click on the one of the buttons, the popup window will appear.

In this window you can assign pressed keystroke sequence to the previously selected button on the Key Action Section. Simply press some keystroke sequence on your everyday-regular-keyboard and press “ok” button (IMPORTANT: patience, this keystroke won’t be triggered by the corresponding key on the BLASTPad device yet – we will talk about saving presets onto the device soon).
This way you can edit all of the buttons on the
Key -Action Section layout. It is super easy.

## Encoder Actions Section

Encoder Actions Section is a list, where each row represent different Encoder Actions. Each column cell (except the one reserved for the name) defines Keystroke/Hotkey.
- To create a new Encoder Action hit “add encoder” button. It will create a new row.
- Double click on the cell with the title “new encoder” to set the Encoder Action‘s name that will appear on the BLASTPad‘s display.
- Click on one of the hotkey cells to assign
keystroke sequence.

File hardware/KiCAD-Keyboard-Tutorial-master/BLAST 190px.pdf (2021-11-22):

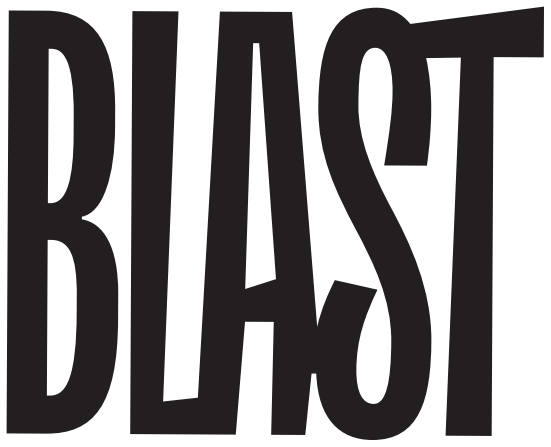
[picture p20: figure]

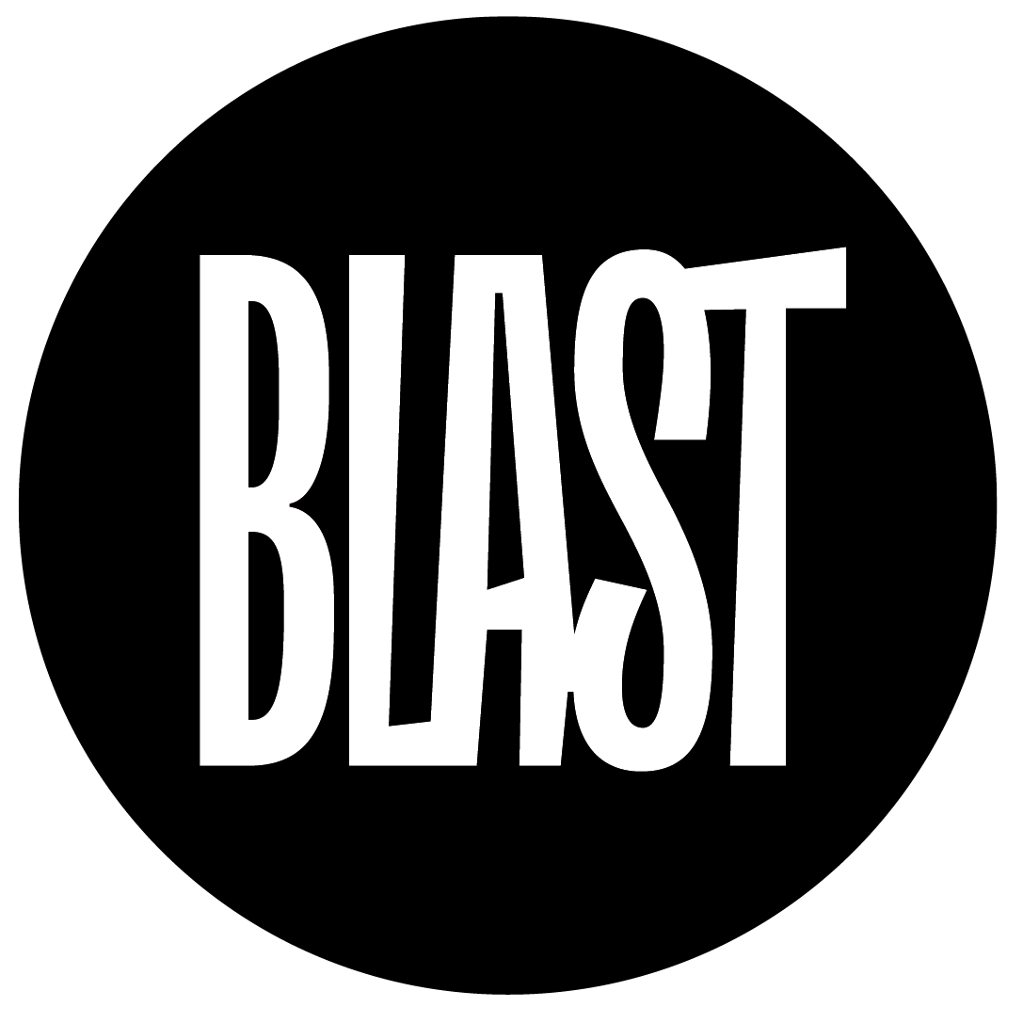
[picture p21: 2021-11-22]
hardware/KiCAD-Keyboard-Tutorial-master/BLAST 190px-01.png

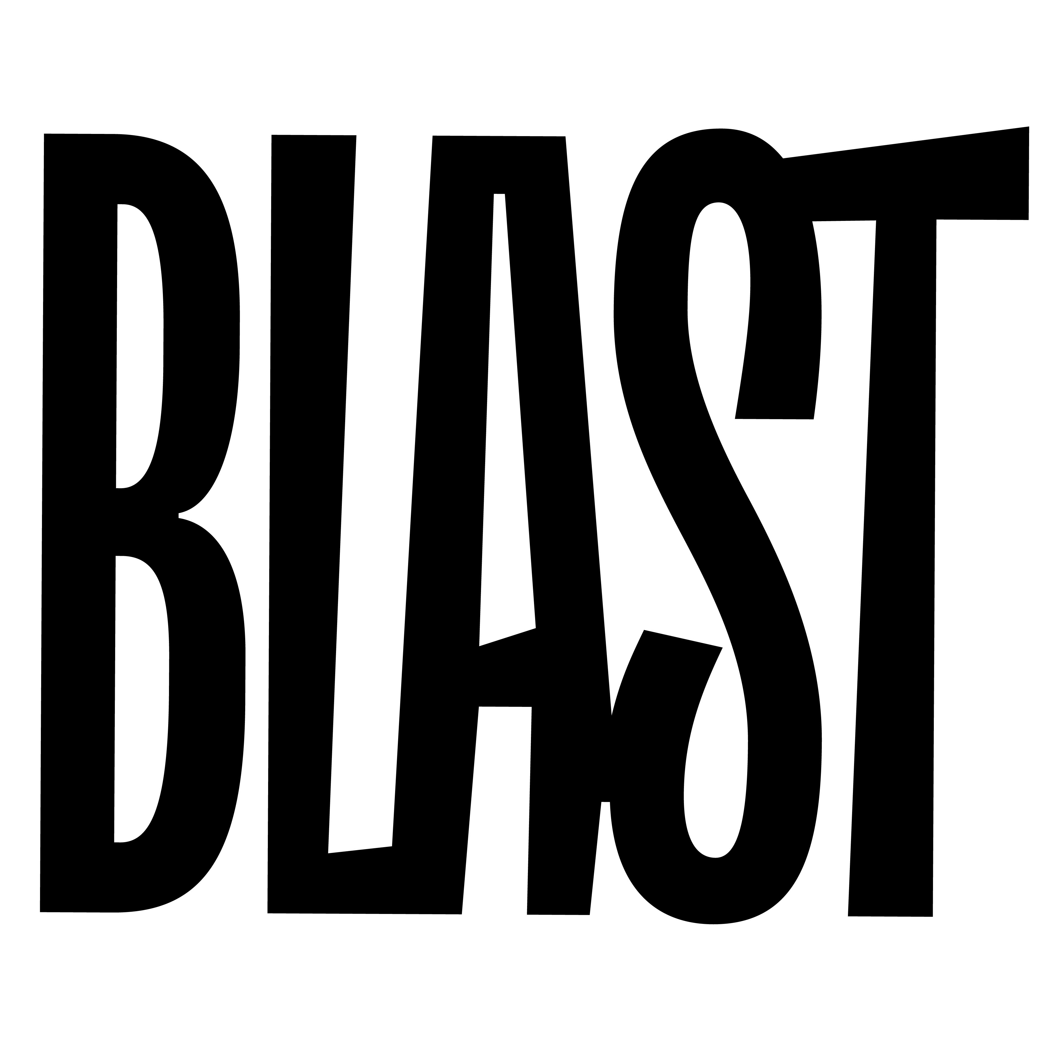
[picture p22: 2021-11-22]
hardware/KiCAD-Keyboard-Tutorial-master/BLAST 90x90-01.png

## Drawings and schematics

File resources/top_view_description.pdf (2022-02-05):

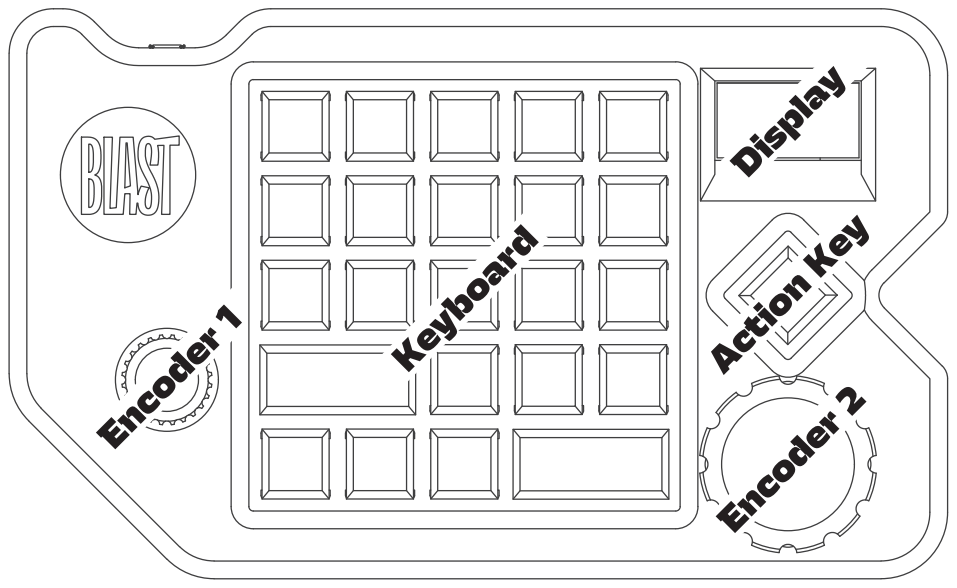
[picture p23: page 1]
Encoder 1; Encoder 2; Keyboard

Display Action Key

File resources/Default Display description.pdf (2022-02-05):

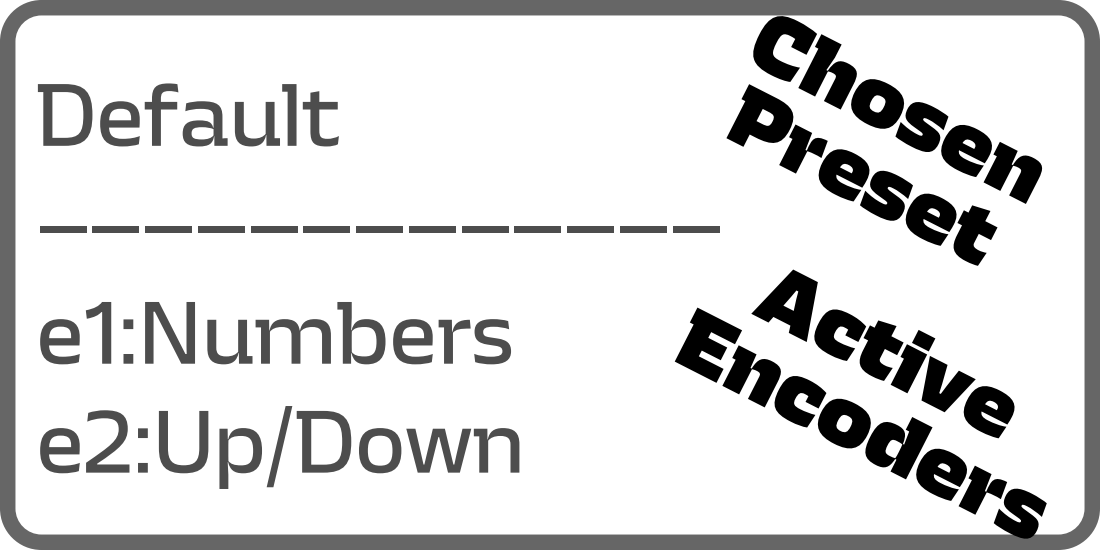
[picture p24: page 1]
Default ––––––––––––– e1:Numbers e2:Up/Down

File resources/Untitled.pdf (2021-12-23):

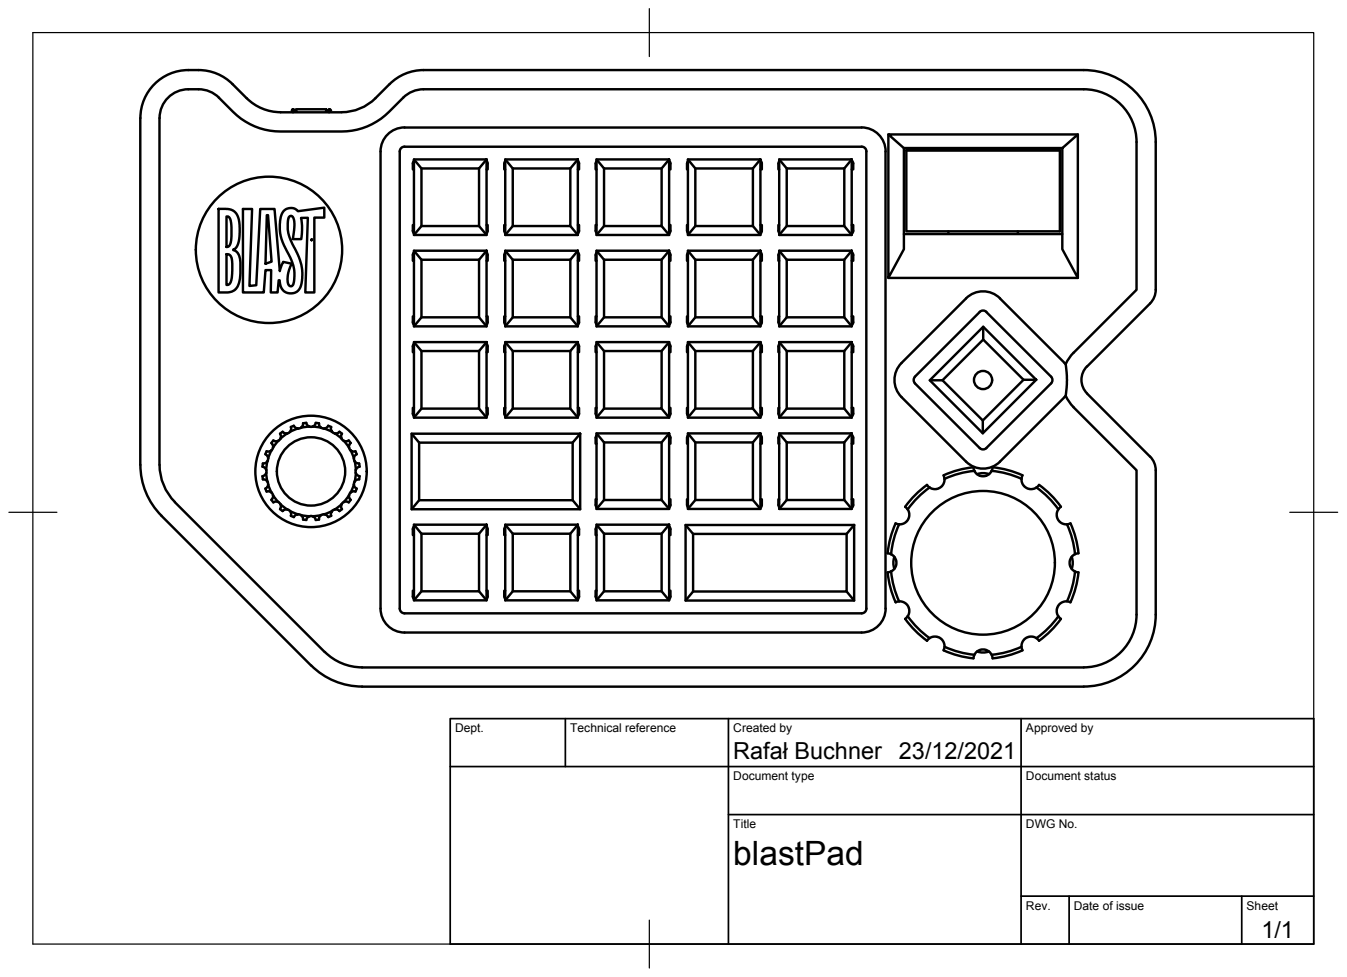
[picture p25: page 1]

Dept. | Technical reference | Created by Rafał Buchner 23/12/2021 | Approved by

Document type | Document status

Title blastPad | DWG No.

Rev. | Date of issue | Sheet 1/1

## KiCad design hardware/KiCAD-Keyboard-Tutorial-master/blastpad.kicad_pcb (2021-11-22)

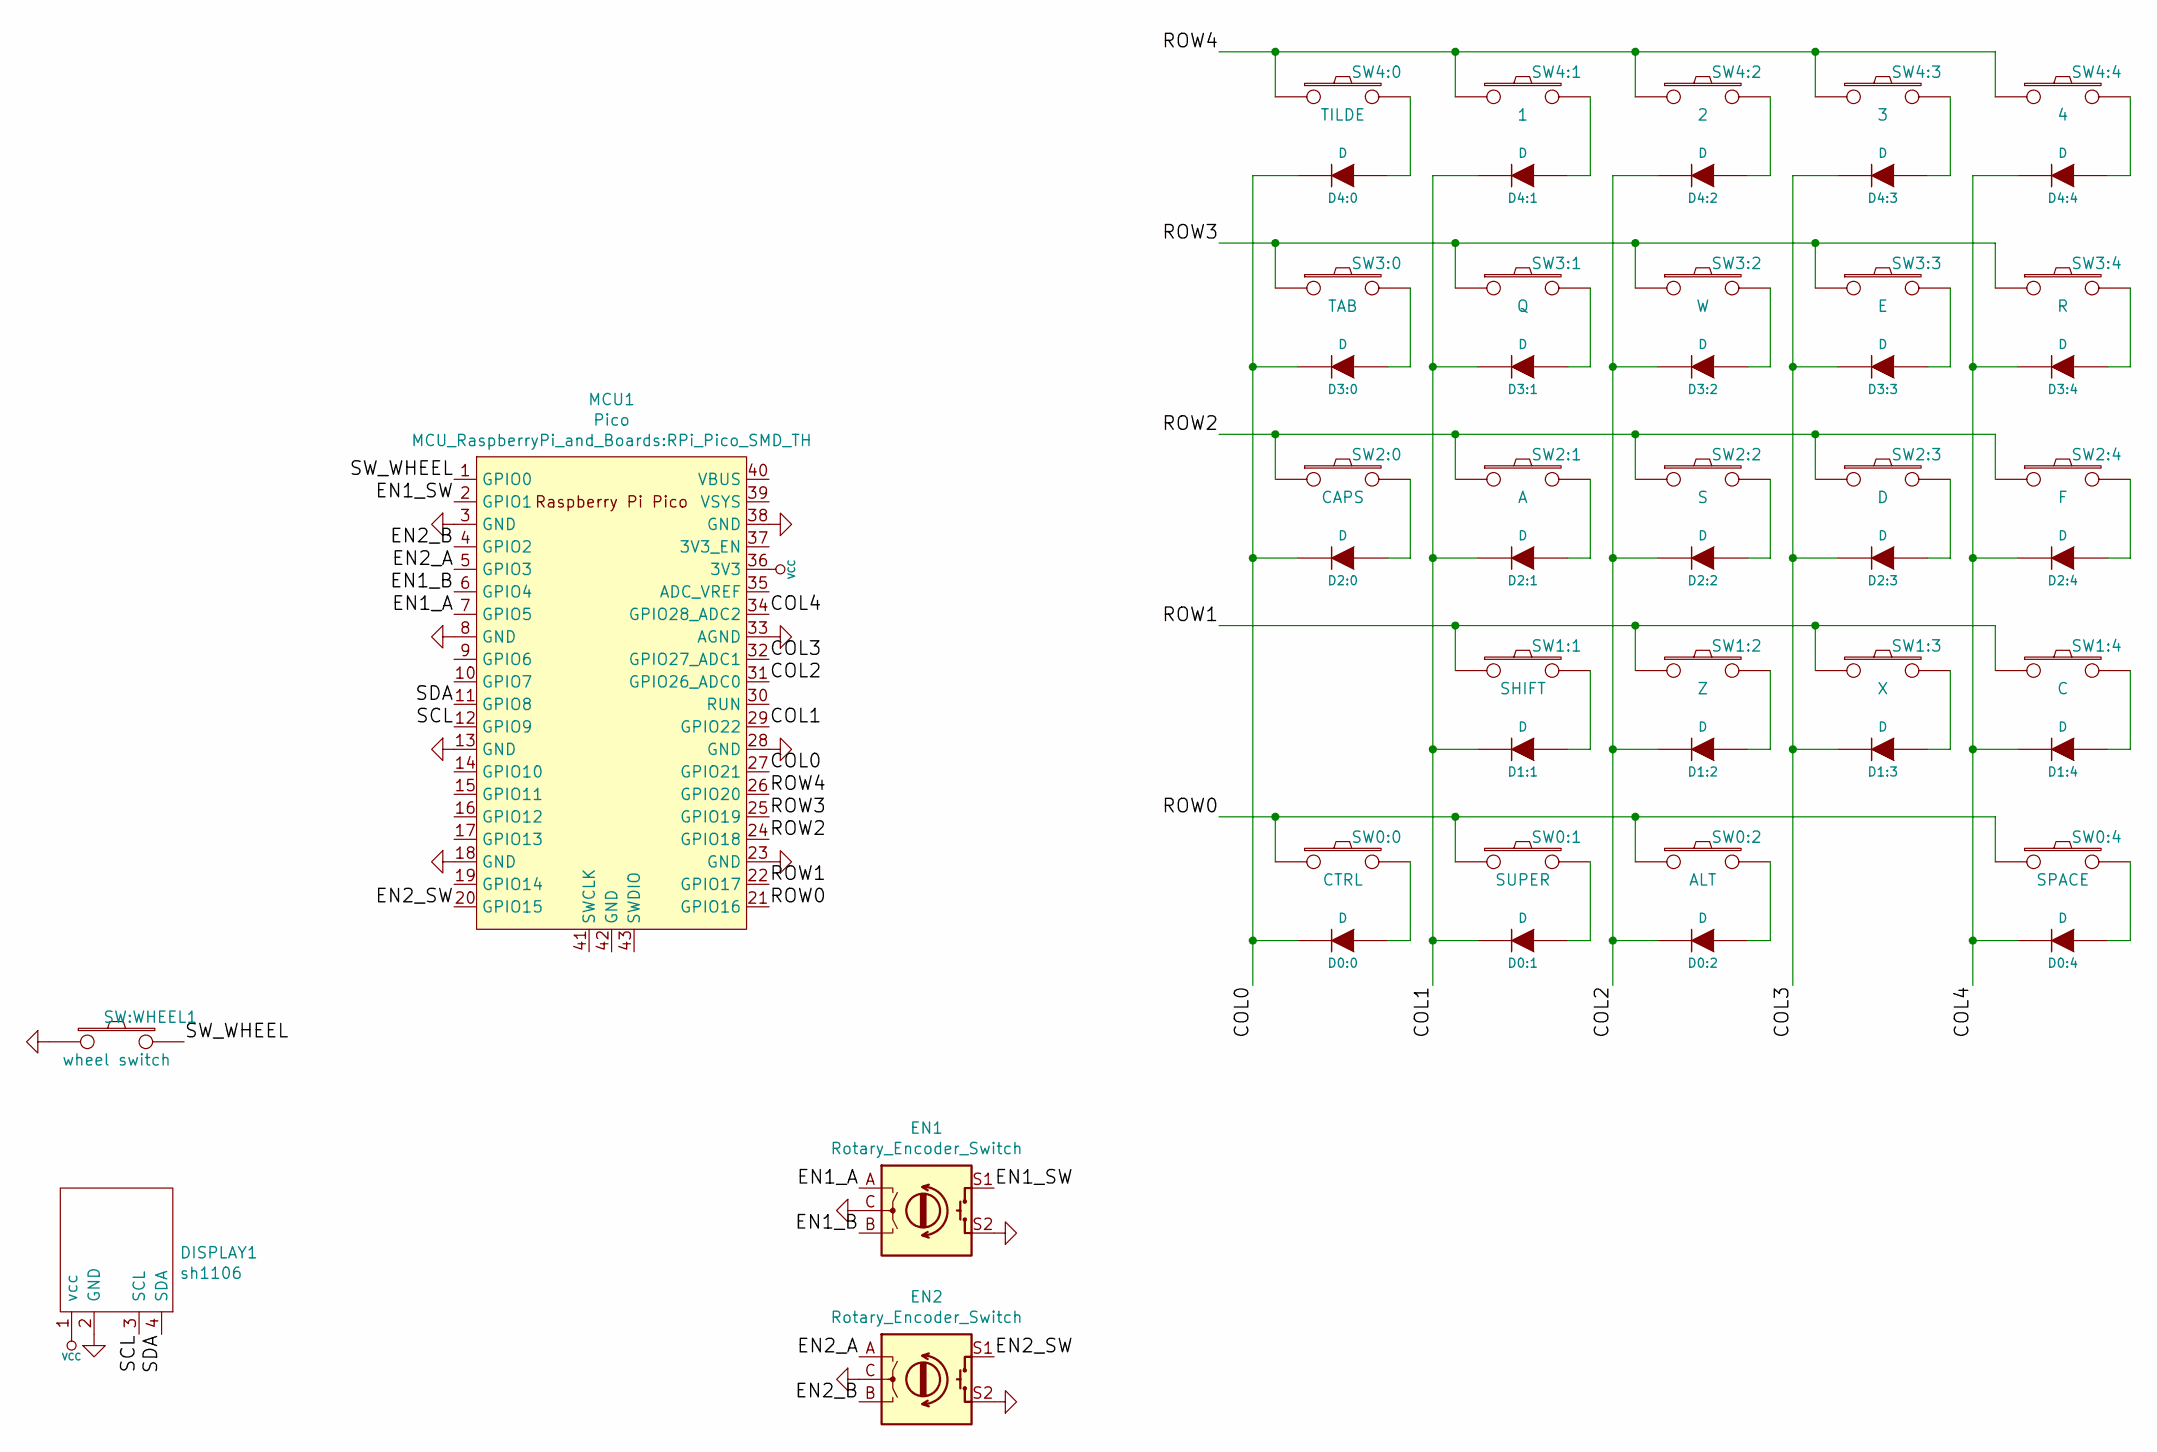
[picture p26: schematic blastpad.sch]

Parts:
D0:0, D0:1, D0:2, D0:4, D1:1, D1:2, D1:3, D1:4, D2:0, D2:1, D2:2, D2:3, D2:4, D3:0, D3:1, D3:2, D3:3, D3:4, D4:0, D4:1, D4:2, D4:3, D4:4: D; DIODE
DISPLAY1: sh1106; 4pin oled display 1,3
EN1, EN2: Rotary_Encoder_Switch; RotaryEncoder_Alps_EC12E-Switch_Vertical_H20mm
MCU1: Pico; RPi_Pico_SMD_TH
SW0:0: CTRL; CHERRY_PCB_100H
SW0:1: SUPER; CHERRY_PCB_100H
SW0:2: ALT; CHERRY_PCB_100H
SW0:4: SPACE; CHERRY_PCB_200H
SW1:1: SHIFT; CHERRY_PCB_200H
SW1:2: Z; CHERRY_PCB_100H
SW1:3: X; CHERRY_PCB_100H
SW1:4: C; CHERRY_PCB_100H
SW2:0: CAPS; CHERRY_PCB_100H
SW2:1: A; CHERRY_PCB_100H
SW2:2: S; CHERRY_PCB_100H
SW2:3: D; CHERRY_PCB_100H
SW2:4: F; CHERRY_PCB_100H
SW3:0: TAB; CHERRY_PCB_100H
SW3:1: Q; CHERRY_PCB_100H
SW3:2: W; CHERRY_PCB_100H
SW3:3: E; CHERRY_PCB_100H
SW3:4: R; CHERRY_PCB_100H
SW4:0: TILDE; CHERRY_PCB_100H
SW4:1: 1; CHERRY_PCB_100H
SW4:2: 2; CHERRY_PCB_100H
SW4:3: 3; CHERRY_PCB_100H
SW4:4: 4; CHERRY_PCB_100H
SW:WHEEL1: wheel switch; CHERRY_PCB_100H

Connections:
/COL0: D0:0.2 (K), D2:0.2 (K), D3:0.2 (K), D4:0.2 (K), MCU1.27 (GPIO21)
/COL1: D0:1.2 (K), D1:1.2 (K), D2:1.2 (K), D3:1.2 (K), D4:1.2 (K), MCU1.29 (GPIO22)
/COL2: D0:2.2 (K), D1:2.2 (K), D2:2.2 (K), D3:2.2 (K), D4:2.2 (K), MCU1.31 (GPIO26_ADC0)
/COL3: D1:3.2 (K), D2:3.2 (K), D3:3.2 (K), D4:3.2 (K), MCU1.32 (GPIO27_ADC1)
/COL4: D0:4.2 (K), D1:4.2 (K), D2:4.2 (K), D3:4.2 (K), D4:4.2 (K), MCU1.34 (GPIO28_ADC2)
/EN1_A: EN1.A, MCU1.7 (GPIO5)
/EN1_B: EN1.B, MCU1.6 (GPIO4)
/EN1_SW: EN1.S1, MCU1.2 (GPIO1)
/EN2_A: EN2.A, MCU1.5 (GPIO3)
/EN2_B: EN2.B, MCU1.4 (GPIO2)
/EN2_SW: EN2.S1, MCU1.20 (GPIO15)
/ROW0: MCU1.21 (GPIO16), SW0:0.1, SW0:1.1, SW0:2.1, SW0:4.1
/ROW1: MCU1.22 (GPIO17), SW1:1.1, SW1:2.1, SW1:3.1, SW1:4.1
/ROW2: MCU1.24 (GPIO18), SW2:0.1, SW2:1.1, SW2:2.1, SW2:3.1, SW2:4.1
/ROW3: MCU1.25 (GPIO19), SW3:0.1, SW3:1.1, SW3:2.1, SW3:3.1, SW3:4.1
/ROW4: MCU1.26 (GPIO20), SW4:0.1, SW4:1.1, SW4:2.1, SW4:3.1, SW4:4.1
/SCL: DISPLAY1.3 (SCL), MCU1.12 (GPIO9)
/SDA: DISPLAY1.4 (SDA), MCU1.11 (GPIO8)
/SW_WHEEL: MCU1.1 (GPIO0), SW:WHEEL1.2
GND: DISPLAY1.2 (GND), EN1.C, EN1.S2, EN2.C, EN2.S2, MCU1.3 (GND), MCU1.8 (GND), MCU1.13 (GND), MCU1.18 (GND), MCU1.23 (GND), MCU1.28 (GND), MCU1.33 (AGND), MCU1.38 (GND), SW:WHEEL1.1
unnamed: D0:0.1 (A), SW0:0.2
unnamed: D0:1.1 (A), SW0:1.2
unnamed: D0:2.1 (A), SW0:2.2
unnamed: D0:4.1 (A), SW0:4.2
unnamed: D1:1.1 (A), SW1:1.2
unnamed: D1:2.1 (A), SW1:2.2
unnamed: D1:3.1 (A), SW1:3.2
unnamed: D1:4.1 (A), SW1:4.2
unnamed: D2:0.1 (A), SW2:0.2
unnamed: D2:1.1 (A), SW2:1.2
unnamed: D2:2.1 (A), SW2:2.2
unnamed: D2:3.1 (A), SW2:3.2
unnamed: D2:4.1 (A), SW2:4.2
unnamed: D3:0.1 (A), SW3:0.2
unnamed: D3:1.1 (A), SW3:1.2
unnamed: D3:2.1 (A), SW3:2.2
unnamed: D3:3.1 (A), SW3:3.2
unnamed: D3:4.1 (A), SW3:4.2
unnamed: D4:0.1 (A), SW4:0.2
unnamed: D4:1.1 (A), SW4:1.2
unnamed: D4:2.1 (A), SW4:2.2
unnamed: D4:3.1 (A), SW4:3.2
unnamed: D4:4.1 (A), SW4:4.2
VCC: DISPLAY1.1 (vcc), MCU1.36 (3V3)

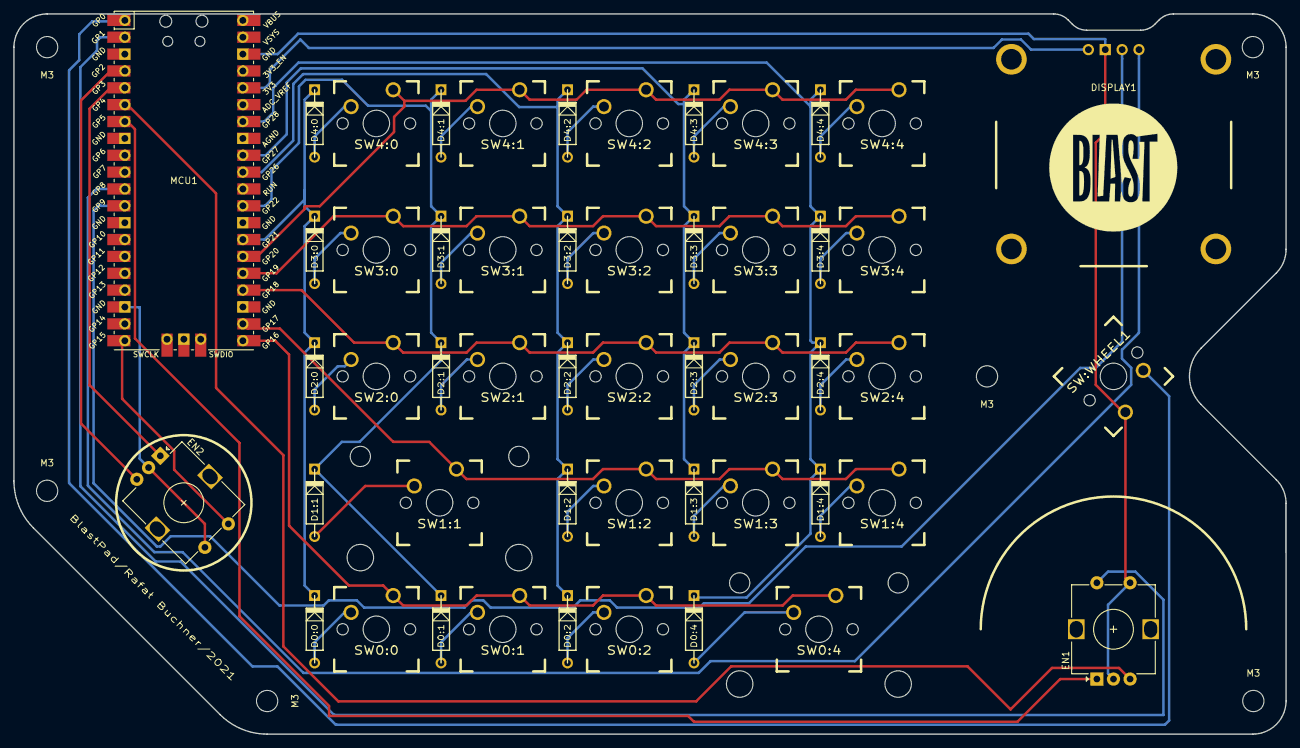
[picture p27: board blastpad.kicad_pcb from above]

Board: 2 copper layers, 191.7 x 108.5 mm, 57 parts (0 on the bottom side), 44 nets.

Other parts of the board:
M3, M3#2, M3#3, M3#4, M3#5, M3#6: MountingHole_3.2mm_M3

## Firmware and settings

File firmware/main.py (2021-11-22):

from macropad import MacroPadUI
from minikbd import MiniKbdButtons
import usb_hid
from adafruit_hid.keyboard import Keyboard
from adafruit_hid.keycode import Keycode
from adafruit_hid.keyboard_layout_us import KeyboardLayoutUS
# print(Keycode.__dict__)
kbd = Keyboard(usb_hid.devices)
kbdLayout = KeyboardLayoutUS(kbd)


ui = MacroPadUI()

# def buttonDownCallback(buttonID, othersDown):
#     kbd.press(Keycode.UP_ARROW)
#     print("btn _down_", buttonID, othersDown)

# def buttonUpCallback(buttonID):
#     kbd.release(Keycode.UP_ARROW)
#     print("btn ^UPUP^", buttonID)


# ButtonMatrix = MiniKbdButtons(
#         keyDownCallback=buttonDownCallback, 
#         keyUpCallback=buttonUpCallback
#     )

while True:
    
    ui.update()
    
    # testEn.update()
    

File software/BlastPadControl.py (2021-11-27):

import sys, os, copy
import json
from collections import OrderedDict
import pprint
from PyQt5 import QtCore, QtGui, QtWidgets

CONFIG_PATH = "/Volumes/BlastPad/configs"

def convertSymbolicToAdafruitNames(shortcut):
    shortcut = [ SYSTEM_KEY_SYMBOLS_Inverted.get(i, i) for i in shortcut ]
    shortcut = [ QT_CONVERSION.get(i, i) for i in shortcut ]
    shortcut = [ QT_TO_ADAFRUIT.get(i, i) for i in shortcut ]
    return shortcut

def convertAdafruitToSymbolicNames(shortcut):
    shortcut = [ QT_TO_ADAFRUIT_Inverted.get(i, i) for i in shortcut ]
    shortcut = [ SYSTEM_KEY_SYMBOLS.get(i, i) for i in shortcut ]
    # shortcut = [ QT_CONVERSION_Inverted.get(i, i) for i in shortcut ]
    return shortcut
    
def convertAdafruitConfigToSymbolic(blastPadDict):
    blastPadDict["shortcuts"] = [convertAdafruitToSymbolicNames(shortcut) for shortcut in blastPadDict["shortcuts"]]
    for enName, shortcuts in blastPadDict["wheels"].items():
        blastPadDict["wheels"][enName] = [convertAdafruitToSymbolicNames(shortcut) for shortcut in shortcuts]
    return blastPadDict

if sys.platform == "darwin":
    QT_CONVERSION = {
            "Meta":"Control",
            "Ctrl":"Command",
            "Alt":"Option",
            "Esc":"Escape",
            "Del":"Delete",
        }
else:
    QT_CONVERSION = {
            "Meta":"Windows",
            "Ctrl":"Control",
            "Esc":"Escape",
            "Del":"Delete",
        }

QT_CONVERSION_Inverted = {v: k for k, v in QT_CONVERSION.items()}


SYSTEM_KEY_SYMBOLS = {
    "Meta":"⌃",
    "Ctrl":"⌘",
    "Command":"⌘",
    "Shift":"⇧",
    "Alt":"⌥",
    "Return":"↵",
    "Enter":"⌤",
    "Up":"↑",
    "Down":"↓",
    "Left":"←",
    "Right":"→",
    "Esc":"⎋",
    "Backspace":"⌫",
    "End":"↘",
    "Home":"↖",
    "Del":"⌦",
    "PgDown":"⇟",
    "PgUp":"⇞",
    "Tab":"⇥",
    "CapsLock":"⇪"

}

SYSTEM_KEY_SYMBOLS_Inverted = {v: k for k, v in SYSTEM_KEY_SYMBOLS.items()}

QT_TO_ADAFRUIT = {
    "1":"ONE",
    "2":"TWO",
    "3":"THREE",
    "4":"FOUR",
    "5":"FIVE",
    "6":"SIX",
    "7":"SEVEN",
    "8":"EIGHT",
    "9":"NINE",
    "0":"ZERO",
    "Enter":"ENTER",
    "Return":"RETURN",
    "Escape":"ESCAPE",
    "Backspace":"BACKSPACE",
    "Tab":"TAB",
    "Space":"SPACEBAR",
    # "Space":"SPACE",
    "-":"MINUS",
    "=":"EQUALS",
    "[":"LEFT_BRACKET",
    "]":"RIGHT_BRACKET",
    "\\":"BACKSLASH",
    "Pound":"POUND", # extra
    ";":"SEMICOLON",
    "'":"QUOTE",
    "`":"GRAVE_ACCENT",
    ",":"COMMA",
    ".":"PERIOD",
    "/":"FORWARD_SLASH",

    "CapsLock":"CAPS_LOCK", # extra

    "F1":"F1", # extra
    "F2":"F2", # extra
    "F3":"F3", # extra
    "F4":"F4", # extra
    "F5":"F5", # extra
    "F6":"F6", # extra
    "F7":"F7", # extra
    "F8":"F8", # extra
    "F9":"F9", # extra
    "F10":"F10", # extra
    "F11":"F11", # extra
    "F12":"F12", # extra

    "PrintScreen":"PRINT_SCREEN", # extra
    "ScrollLock":"SCROLL_LOCK", # extra
    "Pause":"PAUSE", # extra

    "Insert":"INSERT", # extra
    "Home":"HOME", # extra
    "PgUp":"PAGE_UP", # extra
    "Delete":"DELETE", # extra
    "End":"END", # extra
    "PgDown":"PAGE_DOWN", # extra

    "Right":"RIGHT_ARROW", # extra
    "Left":"LEFT_ARROW", # extra
    "Down":"DOWN_ARROW", # extra
    "Up":"UP_ARROW", # extra

    "Keypad_Numlock":"KEYPAD_NUMLOCK", # extra
    "Keypad_Slash":"KEYPAD_FORWARD_SLASH", # extra
    "Keypad_Asterisk":"KEYPAD_ASTERISK", # extra
    "Keypad_Minus":"KEYPAD_MINUS", # extra
    "Keypad_Plus":"KEYPAD_PLUS", # extra
    "Keypad_Enter":"KEYPAD_ENTER", # extra
    "Keypad_One":"KEYPAD_ONE", # extra
    "Keypad_Two":"KEYPAD_TWO", # extra
    "Keypad_Three":"KEYPAD_THREE", # extra
    "Keypad_Four":"KEYPAD_FOUR", # extra
    "Keypad_Five":"KEYPAD_FIVE", # extra
    "Keypad_Six":"KEYPAD_SIX", # extra
    "Keypad_Seven":"KEYPAD_SEVEN", # extra
    "Keypad_Eight":"KEYPAD_EIGHT", # extra
    "Keypad_Nine":"KEYPAD_NINE", # extra
    "Keypad_Zero":"KEYPAD_ZERO", # extra
    "Keypad_Period":"KEYPAD_PERIOD", # extra
    "Keypad_Backslash":"KEYPAD_BACKSLASH", # extra

    "Application":"APPLICATION", # extra
    "Power":"POWER", # extra
    "Keypad_Equals":"KEYPAD_EQUALS", # extra
    "F13":"F13", # extra
    "F14":"F14", # extra
    "F15":"F15", # extra
    "F16":"F16", # extra
    "F17":"F17", # extra
    "F18":"F18", # extra
    "F19":"F19", # extra

    "F20":"F20", # extra
    "F21":"F21", # extra
    "F22":"F22", # extra
    "F23":"F23", # extra
    "F24":"F24", # extra

    "Left_Control":"LEFT_CONTROL", # extra
    "Control":"CONTROL", # extra
    "Left_Shift":"LEFT_SHIFT", # extra
    "Shift":"SHIFT", # extra
    "Left_Alt":"LEFT_ALT", # extra
    "Alt":"ALT", # extra
    "Option":"OPTION", # extra
    "Left_Gui":"LEFT_GUI", # extra
    "Gui":"GUI", # extra
    "Windows":"WINDOWS", # extra
    "Command":"COMMAND", # extra
    "Right_Control":"RIGHT_CONTROL", # extra
    "Right_Shift":"RIGHT_SHIFT", # extra
    "Right_Alt":"RIGHT_ALT", # extra
    "Right_Gui":"RIGHT_GUI", # extra
}

QT_TO_ADAFRUIT_Inverted = {v: k for k, v in QT_TO_ADAFRUIT.items()}


SHIFT_FIX = {
        "~": "`",
        "!": "1",
        "@": "2",
        "#": "3",
        "$": "4",
        "%": "5",
        "^": "6",
        "&": "7",
        "*": "8",
        "(": "9",
        ")": "0",
        "_": "-",
        "+": "=",
        "{": "[",
        "}": "]",
        ":": ";",
        '"': "'",
        "<": ",",
        ">": ".",
        "?": "/",

        }

DEFAULT_HOTKEYS = [ convertAdafruitToSymbolicNames(shortcut) for shortcut in  [['ONE'], ['TWO'], ['THREE'], ['FOUR'], ['FIVE'], ['TAB'], ['Q'], ['W'], ['E'], ['R'], ['CAPS_LOCK'], ['A'], ['S'], ['D'], ['F'], ['SHIFT'], ['Z'], ['X'], ['C'], ['CONTROL'], ['OPTION'], ['COMMAND'], ['SPACE']]]
class KeySequenceEdit(QtWidgets.QKeySequenceEdit):
    def keyPressEvent(self, event):
        super(KeySequenceEdit, self).keyPressEvent(event)
        seq_string = self.keySequence().toString(QtGui.QKeySequence.PortableText)
        t = self.keySequence().toString(QtGui.QKeySequence.NativeText)
        if seq_string:
            last_seq = seq_string.strip()
            if last_seq in SHIFT_FIX.keys() and len(last_seq) == 1:
                last_seq = "Shift+"+SHIFT_FIX[last_seq]
            _last_seq = last_seq.split("+")
            txt = []
            for key in _last_seq:
                if key in SYSTEM_KEY_SYMBOLS.keys():
                    key = SYSTEM_KEY_SYMBOLS[key]
                txt += [key]
            txt = "+".join(txt)
            le = self.findChild(QtWidgets.QLineEdit, "qt_keysequenceedit_lineedit")
            self.setKeySequence(QtGui.QKeySequence(txt))
            le.setText(txt)
            self.editingFinished.emit()
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

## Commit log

2021-10-12 name change
    [tutorial-2021-10-12-17-50-00.sch, tutorial-2021-10-12-17-52-53.sch, tutorial-2021-10-12-18-12-38.sch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]
2021-10-13 pcb designed 1
    [tutorial-2021-10-12-17-50-00-2021-10-12-23-20-50.sch, tutorial-2021-10-12-18-12-38-2021-10-12-23-21-12.sch, tutorial.kicad_pcb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]
2021-10-16 pcb polished
    [360.step, 360.stp, test.stp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]
2021-10-16 hardware name change to blastpad
    [blastpad.kicad_pcb, blastpad.sch]
2021-11-22 backup update
    [BLAST 190px.dxf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]
2021-11-26 huge update
    [MetricsMachine.json]
